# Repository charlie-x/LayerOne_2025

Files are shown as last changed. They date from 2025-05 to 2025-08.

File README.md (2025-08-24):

# LayerOne 2025 GLiTCh BadgE

later on there are ai generated docs...

altium link.. there is an eror on one of the leds on the charlieplex'd leds...
also the 3 pin JST SWD is reversed
.
https://365.altium.com/files/01BF9671-6FB8-4A9E-9FD1-49A52BA8D165

first flash drive appears as RPI-RP2 copy the uf2 file to it, after that use the system command to reboot to the dfu or hold the RP-BOOT button during power on or a reset cycle

the pico-ice can be used to test the  fpga.

https://a360.co/4dxIxcs
terminal is CR, so do cr/lf conversion.

for 3v3 control the pads need to be soldered on the pcb,

switch_pwr  
short 1-2


glitch_ctrl
solder all three
short 1-2-3


3cv3_ctrl
short 1-2-3


fet
short 1-2-3


https://a360.co/4dxIxcs

thea re two pots vr1, vr2 , vr1 changes run votlage of vtg, vr2 controls the low voltage

diag scripts will find

Serial Ports for CMSIS-DAP
==========================

Found serial ports:
crw-rw-rw-  1 root  wheel  0x9000003 May 25 08:40 /dev/cu.usbmodem1202

first serial port is the CDC
crw-rw-rw-  1 root  wheel  0x9000005 May 25 08:40 /dev/cu.usbmodem14301

is for hook up to the fpga etc
crw-rw-rw-  1 root  wheel  0x9000009 May 25 08:40 /dev/cu.usbmodem14303

adc streaming , two adc's interlevaed see the adc python script

crw-rw-rw-  1 root  wheel  0x9000007 May 25 08:40 /dev/cu.usbmodem14305

the adc streaming is seperate and always runs

// run it
python adc_stream_reader.py /dev/cu.usbmodem14305

// pack ADC values into buffer
 - #define HEADER_BYTE 0xAA
 - #define PACKET_SIZE 5
 - 
 - void pack_adc_values(uint16_t _adc0, uint16_t _adc1, uint8_t seq, uint8_t* buffer) {
 -    buffer[0] = HEADER_BYTE;                      // header byte for synchronization
 -    buffer[1] = seq;                              // sequence number
 -     buffer[2] = _adc0 & 0xFF;                      // low 8 bits of adc0
 -     buffer[3] = ((_adc0 >> 8) & 0x0F) |            // high 4 bits of adc0
 -                 ((_adc1 & 0x0F) << 4);             // low 4 bits of adc1
 -     buffer[4] = (_adc1 >> 4) & 0xFF;               // high 8 bits of adc1
 - }



tats for LayerOne2025 codebase:

  Files by type:
  - C (.c): 57 files
  - Headers (.h): 48 files
  - Python (.py): 25 files
  - Markdown (.md): 17 files
  - Shell scripts (.sh): 8 files

  Code metrics:
  - Total lines of code: ~30,383 lines
  - Total commits: 82
  - Contributors: 2 (charliex: 82)

  Top directories:
  - Root directory (372 files)
  - cli/ (42 files)
  - docs/ (12 files)

## Overview

The LayerOne 2025 GLiTCh BadgE is a versatile hardware hacking platform designed for security researchers, hardware enthusiasts, and anyone interested in exploring digital electronics. It combines a powerful RP2040 microcontroller with specialized hardware for glitching, debugging, and interfacing with other devices.

## Features

- **RP2040 Microcontroller** - Dual-core ARM Cortex-M0+ processor
- **ICE40 FPGA** - Programmable logic for custom hardware implementations
- **Voltage Glitcher** - For performing precise voltage glitching attacks
- **Crowbar Circuit** - For power line manipulation
- **SWD Interface** - For debugging ARM-based targets
- **AVRISP** - For programming AVR microcontrollers
- **Analog Monitoring** - For capturing and analyzing signals
- **Multiple USB Modes** - Normal, DAP, and DFU modes for different use cases
- **Basic Logic Analyser** - Simple 12 bit LA at about 10khz
  
## Documentation

Comprehensive documentation is available in the [docs](docs/) directory:

- [Quick Start Guide](docs/quick_start.md) - Get up and running with your badge
- [CLI User Guide](docs/cli_user_guide.md) - Learn how to use the Command Line Interface
- [USB Modes Guide](docs/usb_modes_guide.md) - Understand the different USB modes
- [Hardware Hacking Guide](docs/hardware_hacking_guide.md) - Explore the hardware hacking features
- [Glitching Techniques Guide](docs/glitching_techniques.md) - Detailed guide on voltage, reset, and crowbar glitching
- [ADC Signal Analysis Guide](docs/adc_signal_analysis.md) - How to use the ADC for signal capture and analysis
- [AVRISP Programming Guide](docs/avrisp_programming_guide.md) - Program AVR microcontrollers with the badge
- [Documenting Research](docs/documenting_research.md) - Best practices for documenting hardware security research
- [Command Reference](docs/command_reference.md) - Quick reference for all CLI commands
- [Case Studies](docs/case_studies/README.md) - Real-world examples of hardware security vulnerabilities
  - [nRF52 Glitch Attack](docs/case_studies/nrf52_glitch_attack.md) - Voltage glitching attack on Nordic's BLE SoC

## Getting Started

### Prerequisites

- Python 3.6 or higher
- PySerial library (`pip install pyserial`)
- PyOCD for debugging (`pip install pyocd`)

### Installation

1. Clone this repository:
   ```
   git clone git@github.com:charlie-x/LayerOne_2025.git
   cd LayerOne_2025
   ```

2. Connect your badge to your computer using a USB-C cable
   Either use the RP-BOOT switch to put the badge into RPI-RP2 mode while its in reset, or switch on. or if its already flashed you can use system dfu command on the badge itself, copy the uf2/layerOne2025.uf2 file to the RPI-RP2 folder, use -X if you use cp in Mac OS
  
4. Run the CLI terminal:
   ```
   python3 cli_terminal.py
   ```

### Basic Usage

Once connected to the CLI, you can use commands like:

```
help            # Show available commands
status          # Show badge status
rgb on          # Turn on the RGB LED
usb mode dap    # Switch to DAP mode
```

For a complete list of commands, see the [Command Reference](docs/command_reference.md).

## USB Modes

The badge supports three USB modes:

1. **Normal Mode** (default) - 3 CDC interfaces + Mass Storage
2. **DAP Mode** - CMSIS-DAP debugging interface + CDC
3. **DFU Mode** - Device Firmware Update mode

To switch between modes, use the `usb mode` command:

```
usb mode normal     # Switch to normal mode
usb mode dap        # Switch to DAP mode
usb mode dfu        # Switch to DFU mode
```

## Logic Analyser mode

use command 

adc_stream la



## Development

### Building the Firmware

To build the firmware:

```
./build.sh
```

### Flashing the Firmware

To build and flash the firmware:

```
./build_and_flash.sh
```

### Running Tests

To run the USB mode tests:

```
python3 test_usb_modes.py
```

## Contributing

We welcome contributions to improve the badge and its documentation! Please see the [Contributing Guide](docs/contributing.md) for details on how to contribute.

## License

The LayerOne 2025 GLiTCh BadgE firmware and hardware designs are licensed under [MIT License](https://opensource.org/licenses/MIT).

## Acknowledgments

The LayerOne 2025 GLiTCh BadgE was created by NullSpaceLabs for the LayerOne 2025 conference. Special thanks to all the contributors and the hardware hacking community for their support and inspiration.

## Contact

- Website: [nullspacelabs.com](https://nullspacelabs.com)
- Email: [info@nullspacelabs.com](mailto:info@nullspacelabs.com)
- Twitter: [@nullspacelabs](https://twitter.com/nullspacelabs)

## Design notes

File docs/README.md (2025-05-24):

# LayerOne 2025 GLiTCh BadgE Documentation

Welcome to the official documentation for the LayerOne 2025 GLiTCh BadgE! This documentation will help you get the most out of your badge and explore its many features.

## About the Badge

The LayerOne 2025 GLiTCh BadgE is a versatile hardware hacking platform designed for security researchers, hardware enthusiasts, and anyone interested in exploring digital electronics. It combines a powerful RP2040 microcontroller with specialized hardware for glitching, debugging, and interfacing with other devices.



## Documentation Guides

### Getting Started

- [Quick Start Guide](quick_start.md) - Get up and running with your badge
- [CLI User Guide](cli_user_guide.md) - Learn how to use the Command Line Interface
- [USB Modes Guide](usb_modes_guide.md) - Understand the different USB modes and how to use them

### Features and Capabilities

- [Hardware Hacking Guide](hardware_hacking_guide.md) - Explore the hardware hacking features
- [Glitching Techniques Guide](glitching_techniques.md) - Detailed guide on voltage, reset, and crowbar glitching
- [ADC Signal Analysis Guide](adc_signal_analysis.md) - How to use the ADC for signal capture and analysis
- [AVRISP Programming Guide](avrisp_programming_guide.md) - Program AVR microcontrollers with the badge
- [Documenting Research](documenting_research.md) - Best practices for documenting hardware security research
- [FPGA Programming Guide](fpga_guide.md) - Learn how to program the onboard FPGA
- [Debugging Guide](debugging_guide.md) - Use the badge as a debugging tool

### Development

- [Firmware Development](firmware_dev.md) - Develop custom firmware for the badge
- [Hardware Reference](hardware_reference.md) - Technical details about the badge hardware
- [API Reference](api_reference.md) - Software API documentation

### Case Studies

- [Hardware Security Case Studies](case_studies/README.md) - Real-world examples of hardware security vulnerabilities
  - [nRF52 Glitch Attack](case_studies/nrf52_glitch_attack.md) - Voltage glitching attack on Nordic's BLE SoC

## Command Reference

For a quick reference of all available CLI commands, see the [Command Reference](command_reference.md).

## USB Modes

The badge supports three USB modes:

1. **Normal Mode** - 3 CDC interfaces + Mass Storage
2. **DAP Mode** - CMSIS-DAP debugging interface + CDC
3. **DFU Mode** - Device Firmware Update mode

For details on how to use these modes, see the [USB Modes Guide](usb_modes_guide.md).

## Hardware Hacking Features

The badge includes several specialized hardware features:

- Voltage Glitcher
- Crowbar Circuit
- SWD Interface
- AVRISP
- Analog Monitoring
- Programmable FPGA

For details on how to use these features, see the [Hardware Hacking Guide](hardware_hacking_guide.md).

## Community Resources

- [Official Website](https://nullspacelabs.com)
- [GitHub Repository](https://github.com/nullspacelabs/layerOne2025)
- [Community Forum](https://forum.nullspacelabs.com)
- [Discord Channel](https://discord.gg/nullspacelabs)

## Contributing

We welcome contributions to improve the badge and its documentation! Please see the [Contributing Guide](contributing.md) for details on how to contribute.

## License

The LayerOne 2025 GLiTCh BadgE documentation is licensed under [CC BY-SA 4.0](https://creativecommons.org/licenses/by-sa/4.0/).

The firmware and hardware designs are licensed under [MIT License](https://opensource.org/licenses/MIT).

## Acknowledgments

The LayerOne 2025 GLiTCh BadgE was created by NullSpaceLabs for the LayerOne 2025 conference. Special thanks to all the contributors and the hardware hacking community for their support and inspiration.

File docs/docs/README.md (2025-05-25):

# LayerOne 2025 GLiTCh BadgE Documentation

Welcome to the official documentation for the LayerOne 2025 GLiTCh BadgE! This documentation will help you get the most out of your badge and explore its many features.

## About the Badge

The LayerOne 2025 GLiTCh BadgE is a versatile hardware hacking platform designed for security researchers, hardware enthusiasts, and anyone interested in exploring digital electronics. It combines a powerful RP2040 microcontroller with specialized hardware for glitching, debugging, and interfacing with other devices.



## Documentation Guides

### Getting Started

- [Quick Start Guide](quick_start.md) - Get up and running with your badge
- [CLI User Guide](cli_user_guide.md) - Learn how to use the Command Line Interface
- [USB Modes Guide](usb_modes_guide.md) - Understand the different USB modes and how to use them

### Features and Capabilities

- [Hardware Hacking Guide](hardware_hacking_guide.md) - Explore the hardware hacking features
- [Glitching Techniques Guide](glitching_techniques.md) - Detailed guide on voltage, reset, and crowbar glitching
- [ADC Signal Analysis Guide](adc_signal_analysis.md) - How to use the ADC for signal capture and analysis
- [AVRISP Programming Guide](avrisp_programming_guide.md) - Program AVR microcontrollers with the badge
- [Documenting Research](documenting_research.md) - Best practices for documenting hardware security research

### Development

### Case Studies

- [Hardware Security Case Studies](case_studies/README.md) - Real-world examples of hardware security vulnerabilities
  - [nRF52 Glitch Attack](case_studies/nrf52_glitch_attack.md) - Voltage glitching attack on Nordic's BLE SoC

## Command Reference

For a quick reference of all available CLI commands, see the [Command Reference](command_reference.md).

## USB Modes

The badge supports three USB modes:

1. **Normal Mode** - 3 CDC interfaces + Mass Storage
2. **DAP Mode** - CMSIS-DAP debugging interface + CDC
3. **DFU Mode** - Device Firmware Update mode

Switch between modes using:
```
usb mode normal    # Normal mode (default)
usb mode dap       # CMSIS-DAP mode
usb mode dfu       # Firmware update mode
```

For details on how to use these modes, see the [USB Modes Guide](usb_modes_guide.md).

## Hardware Hacking Features

The badge includes several specialised hardware features:

- **Voltage Glitcher** - Precise voltage glitching attacks
- **Crowbar Circuit** - Power line manipulation
- **SWD Interface** - ARM Cortex-M debugging
- **AVRISP/AVRISP2** - AVR microcontroller programming
- **Analog Monitoring** - ADC for signal capture and analysis
- **ICE40 FPGA** - Programmable logic for custom implementations
- **GPIO Control** - Flexible pin control and interfacing
- **Script System** - Automated command execution

For details on how to use these features, see the [Hardware Hacking Guide](hardware_hacking_guide.md).

## Community Resources

- [Official Website](https://nullspacelabs.com)
- [GitHub Repository](https://github.com/nullspacelabs/layerOne2025)
- [Community Forum](https://forum.nullspacelabs.com)
- [Discord Channel](https://discord.gg/nullspacelabs)

## Contributing

We welcome contributions to improve the badge and its documentation! Please see the [Contributing Guide](contributing.md) for details on how to contribute.

## License

The LayerOne 2025 GLiTCh BadgE documentation is licensed under [CC BY-SA 4.0](https://creativecommons.org/licenses/by-sa/4.0/).

The firmware and hardware designs are licensed under [MIT License](https://opensource.org/licenses/MIT).

## Acknowledgments

The LayerOne 2025 GLiTCh BadgE was created by NullSpaceLabs for the LayerOne 2025 conference. Special thanks to all the contributors and the hardware hacking community for their support and inspiration.

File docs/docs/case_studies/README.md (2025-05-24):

# LayerOne 2025 GLiTCh BadgE - Hardware Security Case Studies

This directory contains case studies of real-world hardware security vulnerabilities and how they can be explored using the LayerOne 2025 GLiTCh BadgE. These case studies provide practical examples of the techniques described in the main documentation.

## Available Case Studies

### [nRF52 Glitch Attack](nrf52_glitch_attack.md)

A detailed examination of the voltage glitching vulnerability discovered in Nordic Semiconductor's nRF52 series of Bluetooth Low Energy SoCs. This case study covers:

- Background on the nRF52 and its security features
- Technical details of the vulnerability
- Step-by-step procedure for reproducing the attack with the GLiTCh BadgE
- Analysis of why the attack works
- Countermeasures and lessons learned

## Purpose of Case Studies

These case studies serve several important purposes:

1. **Educational Value**: They provide concrete examples of hardware security concepts
2. **Practical Application**: They demonstrate how to apply the badge's features to real-world scenarios
3. **Research Guidance**: They offer methodologies that can be adapted to other targets
4. **Documentation Examples**: They show how to document hardware security research effectively

## Responsible Use

The information in these case studies is provided for educational and research purposes only. When reproducing these attacks or applying similar techniques to other devices:

1. Only test devices you own or have explicit permission to test
2. Follow responsible disclosure practices if you discover new vulnerabilities
3. Consider the legal and ethical implications of your research
4. Document your findings thoroughly and accurately

## Contributing Case Studies

We welcome contributions of additional case studies. If you've used the LayerOne 2025 GLiTCh BadgE to explore hardware security vulnerabilities, consider documenting your work and submitting it as a case study.

Guidelines for case study submissions:

1. Follow the format of existing case studies
2. Include clear setup instructions specific to the GLiTCh BadgE
3. Provide background information on the target device
4. Document the attack procedure in detail
5. Include analysis of why the attack works
6. Discuss countermeasures and lessons learned
7. Cite references and prior work appropriately

## Planned Future Case Studies

We plan to add more case studies covering:

- Glitching attacks on secure bootloaders
- Power analysis of cryptographic implementations
- Fault injection in smart cards
- Clock glitching techniques
- Combined glitching and side-channel attacks

Check back regularly for updates, or subscribe to the repository for notifications of new case studies.

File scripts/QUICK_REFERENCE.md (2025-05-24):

# LayerOne 2025 Badge Scripting Language - Quick Reference

## Basic Syntax

- One command per line
- Lines starting with `#` are comments
- Variables are created automatically when assigned
- No declaration needed for variables
- Case-sensitive

## Commands

### System Commands

| Command | Description | Example |
|---|---|---|
| `sleep <time>[ms|us|ns]` | Pause execution | `sleep 100ms` |
| `print <text>` | Output text | `print "Hello, world!"` |
| `exec <command>` | Execute system command | `exec status` |

### GPIO Commands

| Command | Description | Example |
|---|---|---|
| `pin <number> out` | Set pin as output | `pin 25 out` |
| `pin <number> in` | Set pin as input | `pin 2 in` |
| `pin <number> high` | Set pin high | `pin 25 high` |
| `pin <number> low` | Set pin low | `pin 25 low` |
| `pin <number> pullup` | Enable pullup resistor | `pin 2 pullup` |
| `pin <number> pulldown` | Enable pulldown resistor | `pin 2 pulldown` |
| `pin <number> nopull` | Disable pull resistors | `pin 2 nopull` |
| `pin <number> -> <var>` | Read pin state to variable | `pin 2 -> button_state` |

### ADC Commands

| Command | Description | Example |
|---|---|---|
| `adc init <channel>` | Initialize ADC channel | `adc init 0` |
| `adc temp_init` | Initialize temperature sensor | `adc temp_init` |
| `adc <channel> -> <var>` | Read ADC value to variable | `adc 0 -> pot_value` |
| `adc temp -> <var>` | Read temperature to variable | `adc temp -> temp_raw` |

### Control Flow

| Command | Description | Example |
|---|---|---|
| `if <condition>` | Start conditional block | `if pot_value > 100` |
| `else` | Alternative execution path | `else` |
| `endif` | End conditional block | `endif` |
| `loop <count>` | Loop a block of code | `loop 10` |
| `endloop` | End loop block | `endloop` |
| `goto <label>` | Jump to label | `goto start` |
| `<label>:` | Define a label | `start:` |

### Variables and Expressions

| Command | Description | Example |
|---|---|---|
| `<expr> -> <var>` | Assign value to variable | `pot_value * 2 -> doubled_value` |
| `$result` | Special variable with last result | `$result -> last_command_result` |

## Operators

### Arithmetic Operators

| Operator | Description | Example |
|---|---|---|
| `+` | Addition | `a + b -> c` |
| `-` | Subtraction | `a - b -> c` |
| `*` | Multiplication | `a * b -> c` |
| `/` | Division | `a / b -> c` |

### Comparison Operators

| Operator | Description | Example |
|---|---|---|
| `==` | Equal to | `if a == b` |
| `!=` | Not equal to | `if a != b` |
| `<` | Less than | `if a < b` |
| `>` | Greater than | `if a > b` |
| `<=` | Less than or equal to | `if a <= b` |
| `>=` | Greater than or equal to | `if a >= b` |

## Examples

### Blink LED

```
# Blink LED on pin 25
pin 25 out

loop 10
    pin 25 high
    print "LED on"
    sleep 500ms
    pin 25 low
    print "LED off"
    sleep 500ms
endloop
```

### Read Button and Control LED

```
# Set up pins
pin 2 in
pin 2 pullup
pin 25 out

loop 100
    pin 2 -> button
    
    if button == 0
        pin 25 high
        print "Button pressed, LED on"
    else
        pin 25 low
        print "Button released, LED off"
    endif
    
    sleep 10ms
endloop
```

### Read ADC and Control LED Brightness

```
# ADC controlled LED
adc init 0
pin 25 out

loop 100
    adc 0 -> pot_value
    
    if pot_value > 512
        pin 25 high
        print "LED on"
    else
        pin 25 low
        print "LED off"
    endif
    
    sleep 100ms
endloop
```

### Temperature Monitor

```
# Temperature monitor
adc temp_init

loop 60
    adc temp -> temp_raw
    
    # Convert raw value to temperature
    temp_raw * 3300 / 4096 -> millivolts
    millivolts - 706 -> adjusted
    adjusted / 1.721 -> celsius
    
    print "Temperature: " celsius " C"
    
    if celsius > 30
        print "Warning: High temperature!"
    endif
    
    sleep 1000ms
endloop
```

## Limitations

- Maximum script size: 256 lines
- Maximum line length: 128 characters
- Maximum variables: 32
- Maximum labels: 32
- Maximum call stack depth: 16
- Maximum variable name length: 16 characters
- Maximum string length: 64 characters
- Only integer and string data types
- Limited error reporting
- No functions or subroutines
- No arrays or complex data structures

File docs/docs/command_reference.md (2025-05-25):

# LayerOne 2025 GLiTCh BadgE - Command Reference

This document provides a quick reference for all CLI commands available on the LayerOne 2025 GLiTCh BadgE.

## Command Syntax

Commands follow this general syntax:
```
command [subcommand] [parameters]
```

For detailed help on any command, use:
```
help [command]
```

## General Commands

| Command | Description | Example |
|---|---|---|
| `help [command]` | Show help for all commands or a specific command | `help usb` |
| `status [subsystem]` | Show status of all systems or a specific subsystem | `status gpio` |

## Hardware Control

### RGB LED Control

| Command | Description | Example |
|---|---|---|
| `rgb on` | Turn on all RGB LEDs | `rgb on` |
| `rgb off` | Turn off all RGB LEDs | `rgb off` |
| `rgb r` | Toggle red LED | `rgb r` |
| `rgb g` | Toggle green LED | `rgb g` |
| `rgb b` | Toggle blue LED | `rgb b` |
| `rgb pwm:r,g,b` | Set PWM brightness (0.0-1.0) | `rgb pwm:1.0,0.5,0.0` |

### Power Control

| Command | Description | Example |
|---|---|---|
| `3v3 on` | Turn on the 3.3V rail | `3v3 on` |
| `3v3 off` | Turn off the 3.3V rail | `3v3 off` |

### GPIO Control

| Command | Description | Example |
|---|---|---|
| `gpio` | Show status of all GPIO pins | `gpio` |
| `gpio set <pin> <action>` | Control individual pins | `gpio set 16 high` |
| `pins` | Alias for the `gpio` command | `pins` |

**GPIO Actions:**
- `input` - Set pin as input
- `output [value]` - Set as output with optional value
- `function <func>` - Set pin function
- `high/1` - Set pin high
- `low/0` - Set pin low
- `reset` - Reset pin to default state

## FPGA Commands

| Command | Description | Example |
|---|---|---|
| `ice reset on\|off\|pulse` | Control FPGA reset pin | `ice reset pulse` |
| `ice clock on\|off` | Control 12MHz clock | `ice clock on` |
| `ice done` | Check DONE signal | `ice done` |
| `ice status` | Show FPGA status | `ice status` |
| `ice init` | initialise FPGA interfaces | `ice init` |
| `ice start [source]` | Start FPGA (spi, nvcm, flash) | `ice start spi` |
| `ice stop` | Stop FPGA | `ice stop` |
| `ice spi init\|deinit\|test\|status` | SPI interface control | `ice spi init` |

## Glitching Commands

| Command | Description | Example |
|---|---|---|
| `glitch delay <us>` | Set delay in microseconds | `glitch delay 100` |
| `glitch duration <us>` | Set duration in microseconds | `glitch duration 10` |
| `glitch trigger` | Trigger the glitch generator | `glitch trigger` |
| `glitch status` | Show current settings | `glitch status` |
| `g` | Shortcut to trigger the glitch generator | `g` |

## Crowbar Commands

| Command | Description | Example |
|---|---|---|
| `crowbar delay <us>` | Set delay in microseconds | `crowbar delay 100` |
| `crowbar duration <us>` | Set duration in microseconds | `crowbar duration 5` |
| `crowbar trigger` | Trigger the crowbar circuit | `crowbar trigger` |
| `crowbar status` | Show current settings | `crowbar status` |
| `c` | Shortcut to trigger the crowbar circuit | `c` |

## ADC Commands

| Command | Description | Example |
|---|---|---|
| `adc voltage\|current\|all` | Read ADC values | `adc voltage` |
| `adc_stream start\|stop\|status` | Control ADC streaming to CDC2 | `adc_stream start` |

## Communication Interfaces

### UART Commands

| Command | Description | Example |
|---|---|---|
| `uart send <text>` | Send text to debug UART | `uart send "Hello, World!"` |
| `uart read` | Read from debug UART | `uart read` |

### SWD Commands

| Command | Description | Example |
|---|---|---|
| `swd reset` | Reset SWD interface | `swd reset` |
| `swd read <len>` | Read bytes from SWD | `swd read 4` |
| `swd write <bytes>` | Write hex bytes to SWD | `swd write 0x01 0x02` |
| `swd idcode` | Read CPU ID code | `swd idcode` |

### AVRISP Commands

**Standard AVRISP (fixed pins):**

| Command | Description | Example |
|---|---|---|
| `avrisp init\|deinit` | initialise/deinitialise interface | `avrisp init` |
| `avrisp detect` | Detect AVR chip | `avrisp detect` |
| `avrisp fuses read\|write` | Fuse operations | `avrisp fuses read` |
| `avrisp erase` | Erase chip | `avrisp erase` |
| `avrisp program <file>` | Program hex file | `avrisp program firmware.hex` |
| `avrisp verify <file>` | Verify hex file | `avrisp verify firmware.hex` |
| `avrisp run` | Run AVRISP service on CDC1 | `avrisp run` |

**Configurable AVRISP2/AB:**

| Command | Description | Example |
|---|---|---|
| `avrisp2 init [mode]` | initialise with mode (spi\|bitbang) | `avrisp2 init spi` |
| `avrisp2 init pins <assignments>` | Custom pin assignments | `avrisp2 init pins sck=2 miso=3 mosi=4 reset=5` |
| `avrisp2 pins` | Show/set pin assignments | `avrisp2 pins` |
| `avrisp2 detect\|erase` | Basic operations | `avrisp2 detect` |
| `avrisp2 fuses read\|write` | Fuse operations | `avrisp2 fuses read` |
| `avrisp2 lock read\|on\|off` | Lock bit operations | `avrisp2 lock read` |
| `ab <command>` | Shortcut for avrisp2 commands | `ab detect` |

## System Commands

| Command | Description | Example |
|---|---|---|
| `system reboot` | Reboot the badge | `system reboot` |
| `system dfu` | Reboot into DFU mode | `system dfu` |
| `test [component] [count]` | Run tests with optional repeat count | `test gpio 5` |
| `debug on\|off\|status` | Control debug output | `debug on` |

## USB Commands

| Command | Description | Example |
|---|---|---|
| `usb mode normal` | Switch to normal mode (3 CDC + MSC) | `usb mode normal` |
| `usb mode dap` | Switch to DAP mode (CMSIS-DAP + CDC) | `usb mode dap` |
| `usb mode dfu` | Switch to DFU mode | `usb mode dfu` |
| `usb status` | Show USB status | `usb status` |

## DAP Commands

| Command | Description | Example |
|---|---|---|
| `dap init\|deinit` | initialise/deinitialise DAP | `dap init` |
| `dap status` | Show DAP status | `dap status` |
| `dap connect\|disconnect` | Target connection control | `dap connect` |
| `dap reset` | Reset target | `dap reset` |
| `dap idcode` | Read target IDCODE | `dap idcode` |
| `dap locked` | Check if target is locked | `dap locked` |

## Interface Commands

| Command | Description | Example |
|---|---|---|
| `interface list` | List available interfaces | `interface list` |
| `interface uart0\|uart1\|usb0\|usb1\|usb2` | Switch interface | `interface uart0` |

## File System Commands

| Command | Description | Example |
|---|---|---|
| `ls` | List filesystem contents | `ls` |
| `cat <filename>` | Display file contents | `cat script.txt` |
| `exec <filename>` | Execute command file | `exec startup.txt` |
| `format` | Reinitialise filesystem (erases all) | `format` |

## Script Commands

| Command | Description | Example |
|---|---|---|
| `script run <filename>` | Run script file | `script run test.scr` |
| `script load <filename>` | Load script | `script load test.scr` |
| `script list` | List available scripts | `script list` |
| `script vars` | Show script variables | `script vars` |

## Timing Commands

| Command | Description | Example |
|---|---|---|
| `delay_ns <ns>` | Delay for nanoseconds | `delay_ns 1000` |
| `sleep_ms <ms>` | Sleep for milliseconds | `sleep_ms 100` |

## Easter Eggs

| Command | Description | Example |
|---|---|---|
| `wopr start\|stop\|status` | Control WOPR simulation | `wopr start` |

## Command Parameters

Many commands accept parameters in the following formats:

1. **Positional parameters**:
   ```
   command param1 param2
   ```

2. **Named parameters**:
   ```
   command name1=value1 name2=value2
   ```

3. **Mixed parameters**:
   ```
   command param1 name2=value2
   ```

## Parameter Types

| Type | Description | Example |
|---|---|---|
| Integer | Whole number | `123`, `0x7B` (hex) |
| Float | Decimal number | `3.14` |
| String | Text (quote if it contains spaces) | `"Hello World"` |
| Boolean | True/false value | `true`, `false`, `1`, `0` |
| Pin | GPIO pin number | `16` |
| Address | Memory address | `0x20000000` |

## Common Parameter Names

| Name | Description | Example |
|---|---|---|
| `width` | Width of pulse in clock cycles | `width=10` |
| `delay` | Delay in clock cycles | `delay=100` |
| `repeat` | Number of repetitions | `repeat=3` |
| `trigger` | Trigger source | `trigger=gpio` |
| `pin` | GPIO pin number | `pin=16` |
| `edge` | Edge type for trigger | `edge=rising` |
| `channel` | ADC channel | `channel=0` |
| `baud` | Baud rate for UART | `baud=115200` |
| `tx` | TX pin for UART | `tx=0` |
| `rx` | RX pin for UART | `rx=1` |

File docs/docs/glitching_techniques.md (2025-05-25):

# LayerOne 2025 GLiTCh BadgE - Glitching Techniques Guide

## Introduction

This guide provides detailed information on how to perform various glitching attacks using the LayerOne 2025 GLiTCh BadgE. Glitching is a technique used in hardware security research to manipulate a device's operation by introducing intentional faults, potentially bypassing security measures or causing unexpected behavior.

## Types of Glitching

The badge supports several types of glitching techniques:

1. **Voltage Glitching**: Briefly disrupting the target's power supply voltage
2. **Clock Glitching**: Manipulating the clock signal to cause timing faults
3. **Reset Glitching**: Manipulating the reset line to cause partial resets
4. **Crowbar Glitching**: Using the crowbar circuit to create power shorts
5. **Electromagnetic Glitching**: Using external EM pulses (with additional hardware)

## Hardware Setup

### General Setup

1. Connect your target device to the badge:
   - Target VCC → Badge glitch output
   - Target GND → Badge GND
   - (Optional) Target clock → Badge clock output
   - (Optional) Target reset → Badge reset output

2. Connect monitoring equipment:
   - Badge ADC inputs → Target test points
   - (Optional) External oscilloscope → Badge test points

### Voltage Glitching Setup

For voltage glitching, the badge provides a controlled power output that can be briefly disrupted:

```
┌─────────┐           ┌─────────┐
│         │  Glitch   │         │
│  Badge  ├───Output──┤  Target │
│         │           │         │
└────┬────┘           └────┬────┘
     │                     │
     └─────────GND─────────┘
```

### Crowbar Glitching Setup

For crowbar glitching, the badge can briefly short the target's power supply:

```
┌─────────┐           ┌─────────┐
│         │  VCC      │         │
│  Badge  ├───Output──┤  Target │
│         │           │         │
└────┬────┘           └────┬────┘
     │      Crowbar        │
     └─────Connection──────┘
```

### Reset Glitching Setup

For reset glitching, connect the badge to the target's reset line:

```
┌─────────┐           ┌─────────┐
│         │  Reset    │         │
│  Badge  ├───Output──┤  Target │
│         │           │         │
└────┬────┘           └────┬────┘
     │                     │
     └─────────GND─────────┘
```

## Voltage Glitching Techniques

Voltage glitching involves briefly disrupting the target's power supply to cause instruction skips or memory corruption.

### Basic Voltage Glitch

1. Configure the glitcher:
   ```
   glitch setup width=10 delay=100 repeat=1
   ```

2. Arm the glitcher:
   ```
   glitch arm
   ```

3. Trigger the glitch:
   ```
   glitch trigger
   ```

### Timing-Based Voltage Glitch

To target specific operations, you need to time the glitch precisely:

1. Configure the glitcher with external trigger:
   ```
   glitch delay 10      # Set delay to 10 microseconds
   glitch duration 5    # Set duration to 5 microseconds
   ```

2. Connect monitoring to observe the target's operation

3. Trigger the glitch at the right moment:
   ```
   glitch trigger
   ```
   
   Or use the shortcut:
   ```
   g
   ```

### Glitch Parameter Tuning

Effective glitching requires finding the right parameters. Start with:

1. **Duration**: 5-20 microseconds
2. **Delay**: 0-200 microseconds  

Then perform manual parameter sweeps:

```
glitch delay 50       # Start with 50µs delay
glitch duration 10    # Start with 10µs duration
g                     # Test
glitch delay 60       # Try different delay
g                     # Test again
```

Monitor the target's response to find successful parameters.

## Crowbar Glitching Techniques

Crowbar glitching creates a more aggressive power disruption by briefly shorting the power supply.

### Basic Crowbar Glitch

1. Configure the crowbar:
   ```
   crowbar delay 100     # Set delay to 100 microseconds
   crowbar duration 5    # Set duration to 5 microseconds
   ```

2. Check the settings:
   ```
   crowbar status
   ```

3. Trigger the crowbar:
   ```
   crowbar trigger
   ```
   
   Or use the shortcut:
   ```
   c
   ```

### Timed Crowbar Glitch

For precise timing, you'll need to manually coordinate the timing:

1. Configure the crowbar parameters:
   ```
   crowbar delay 50      # Adjust based on target timing
   crowbar duration 2    # Very short duration
   ```

2. Monitor the target (e.g., via UART) and trigger at the right moment:
   ```
   c                     # Trigger when ready
   ```

### Crowbar vs. Voltage Glitching

- **Crowbar Glitching**: More aggressive, causes deeper voltage drops, works well for devices with large capacitors
- **Voltage Glitching**: More precise, allows finer control, better for sensitive devices

## Reset Glitching Techniques

Reset glitching manipulates the reset line to cause partial resets of the target.

### Basic Reset Glitch

Reset glitching can be achieved using GPIO control:

1. Connect the target's reset line to a GPIO pin on the badge

2. Control the reset line:
   ```
   gpio set 20 output 1  # Set GPIO20 as output high (inactive reset)
   gpio set 20 low       # Pull reset low (active)
   delay_ns 10000        # Brief reset pulse
   gpio set 20 high      # Release reset
   ```

### Reset Glitch During Boot

To target the boot process:

1. Configure timing and coordinate with boot sequence:
   ```
   gpio set 20 low       # Hold in reset
   sleep_ms 100          # Wait
   gpio set 20 high      # Release reset
   sleep_ms 50           # Wait for partial boot
   gpio set 20 low       # Glitch reset
   delay_ns 5000         # Brief glitch
   gpio set 20 high      # Release
   ```

2. Power cycle the target

3. Immediately arm and trigger the reset glitcher:
   ```
   reset_glitch arm
   reset_glitch trigger
   ```

## Using the ADC for Glitch Analysis

The badge's ADC can be used to monitor and analyze glitches in real-time.

### Monitoring Power During Glitches

1. Connect the target's VCC to an ADC input:
   ```
   ┌─────────┐           ┌─────────┐           ┌─────────┐
   │         │  Glitch   │         │           │         │
   │  Badge  ├───Output──┤  Target ├───VCC─────┤  Badge  │
   │         │           │         │           │   ADC   │
   └────┬────┘           └────┬────┘           └─────────┘
        │                     │
        └─────────GND─────────┘
   ```

2. Configure ADC streaming:
   ```
   adc_stream start channel=0 rate=1000000
   ```

3. Perform your glitch

4. Stop ADC streaming and save the data:
   ```
   adc_stream stop
   adc_stream save glitch_capture.csv
   ```

### Trigger-Based Capture

To capture only the glitch event:

1. Configure ADC trigger capture:
   ```
   adc capture channel=0 trigger=falling threshold=2.5 samples=1000 pretrigger=100
   ```

2. Arm the ADC capture:
   ```
   adc capture arm
   ```

3. Perform your glitch

The ADC will automatically capture when the voltage falls below 2.5V, including 100 samples before the trigger.

### Analyzing Glitch Waveforms

Key characteristics to look for in the captured waveforms:

1. **Voltage Drop**: How far the voltage drops during the glitch
2. **Glitch Duration**: The actual duration of the voltage drop
3. **Recovery Time**: How long it takes for the voltage to stabilize
4. **Ringing**: Oscillations after the glitch

Example analysis:
```
Glitch parameters: width=10, delay=100
Measured voltage drop: 3.3V → 1.2V
Measured duration: 120ns
Recovery time: 350ns
Result: Target reset successfully bypassed
```

## Documenting Glitch Attacks

### Standard Documentation Format

When documenting glitch attacks, include:

1. **Target Information**:
   - Device name and model
   - Firmware version
   - Operating conditions

2. **Setup Description**:
   - Connection diagram
   - Equipment used
   - Badge configuration

3. **Glitch Parameters**:
   - Type of glitch (voltage, crowbar, reset)
   - Width, delay, repeat settings
   - Trigger method

4. **Results**:
   - Success rate (e.g., 8/10 attempts successful)
   - Observed behavior
   - Captured waveforms

5. **Analysis**:
   - Why the glitch worked
   - Critical timing points
   - Potential countermeasures

### Example Documentation

```markdown
# Voltage Glitch Attack on XYZ Secure Microcontroller

## Target
- Device: XYZ Secure Microcontroller
- Firmware: v1.2.3
- Operating voltage: 3.3V
- Clock: 16MHz

## Setup
- LayerOne 2025 GLiTCh BadgE connected to target VCC
- Target running authentication routine
- Badge ADC0 monitoring target VCC
- Badge GPIO16 connected to target "processing" LED for trigger

## Glitch Parameters
- Type: Voltage glitch
- Width: 12 clock cycles
- Delay: 85 clock cycles after trigger
- Repeat: 1
- Trigger: Rising edge on GPIO16

## Results
- Success rate: 7/10 attempts
- When successful: Authentication bypassed, access granted
- Captured waveform shows voltage drop from 3.3V to 1.1V for 150ns
- Target continues operation after glitch without reset

## Analysis
- Glitch likely causes the comparison instruction to be skipped
- Critical timing is when the "processing" LED turns on
- The 85-cycle delay targets the exact instruction performing the password check
- Countermeasure: Implement redundant checks or glitch detection
```

## Advanced Techniques

### Multi-Stage Glitching

Some targets require multiple glitches to bypass security:

1. Configure the first glitch:
   ```
   glitch setup width=5 delay=100 name=glitch1
   ```

2. Configure the second glitch:
   ```
   glitch setup width=10 delay=500 name=glitch2
   ```

3. Create a sequence:
   ```
   glitch sequence add glitch1 glitch2 interval=1000
   ```

4. Arm and trigger the sequence:
   ```
   glitch sequence arm
   glitch sequence trigger
   ```

### Combining Glitch Types

For complex targets, combine different glitch types:

```
attack setup type=combined voltage_width=5 voltage_delay=100 reset_width=2 reset_delay=105
attack arm
attack trigger
```

This performs a voltage glitch followed immediately by a reset glitch.

### Fault Injection Campaigns

For systematic research:

1. Define parameter ranges:
   ```
   campaign setup param=width range=5:20:5 param=delay range=0:200:10 iterations=5
   ```

2. Define success criteria:
   ```
   campaign success uart="Access granted" or gpio=16:high
   ```

3. Run the campaign:
   ```
   campaign start
   ```

4. Analyze results:
   ```
   campaign report
   ```

## Troubleshooting

### Glitch Not Working

1. **No Effect on Target**:
   - Increase glitch width
   - Decrease power supply capacitance on target
   - Try crowbar instead of voltage glitch

2. **Target Always Resets**:
   - Decrease glitch width
   - Increase delay
   - Add capacitance to target

3. **Inconsistent Results**:
   - Improve trigger timing
   - Stabilize target operating conditions
   - Use ADC to verify glitch timing

## Conclusion

Glitching is both an art and a science. Success requires:

1. Understanding the target's operation
2. Precise timing and parameter tuning
3. Careful analysis of results
4. Systematic documentation

The LayerOne 2025 GLiTCh BadgE provides all the tools needed for effective glitching research. By combining different techniques and carefully analyzing the results, you can uncover vulnerabilities and better understand hardware security.

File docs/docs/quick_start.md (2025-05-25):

# LayerOne 2025 GLiTCh BadgE - Quick Start Guide

## Introduction

Welcome to your LayerOne 2025 GLiTCh BadgE! This quick start guide will help you get up and running with your badge in just a few minutes.

## What's in the Box

- LayerOne 2025 GLiTCh BadgE
- USB-C cable
- Quick reference card

## Hardware Overview



1. **USB-C Port** - Connect to your computer
2. **RGB LED** - Status indicator
3. **Reset Button** - Reset the badge
4. **User Button** - Programmable button
5. **GPIO Headers** - Connect to external devices
6. **FPGA** - ICE40 FPGA for custom logic
7. **Target Headers** - Connect to target devices for hacking
8. **Power Switch** - Turn the badge on/off

## Getting Started

### Step 1: Connect the Badge

1. Connect the USB-C cable to your badge
2. Connect the other end to your computer
3. The RGB LED should light up, indicating the badge is powered

### Step 2: Install Required Software

#### Python and Dependencies

1. Install Python 3.6 or higher:
   - Windows: Download from [python.org](https://python.org)
   - macOS: `brew install python3`
   - Linux: `sudo apt install python3 python3-pip`

2. Install required Python packages:
   ```
   pip install pyserial pyocd
   ```

### Step 3: Connect to the CLI

1. Download the badge software from [GitHub](https://github.com/nullspacelabs/layerOne2025)
2. Open a terminal and navigate to the downloaded folder
3. Run the CLI terminal script:
   ```
   python3 cli_terminal.py
   ```
4. You should see the badge prompt:
   ```
   badge>
   ```

### Step 4: Test Basic Commands

Try these commands to verify your badge is working:

```
help            # Show available commands
status          # Show badge status
rgb on          # Turn on the RGB LED
rgb off         # Turn off the RGB LED
gpio            # Show GPIO pin status
adc all         # Read all ADC channels
```

## USB Modes

The badge supports three USB modes:

1. **Normal Mode** (default) - 3 CDC interfaces + Mass Storage
2. **DAP Mode** - CMSIS-DAP debugging interface + CDC
3. **DFU Mode** - Device Firmware Update mode

To switch between modes, use the `usb mode` command:

```
usb mode normal     # Switch to normal mode
usb mode dap        # Switch to DAP mode
usb mode dfu        # Switch to DFU mode
```

After switching modes, the badge will reset and re-enumerate as a different USB device.

## Basic Features

### Controlling the RGB LED

```
rgb on          # Turn on all LEDs
rgb off         # Turn off all LEDs
rgb r           # Toggle red LED
rgb g           # Toggle green LED
rgb b           # Toggle blue LED
```

### Reading ADC Values

```
adc all         # Read all ADC channels
adc voltage     # Read voltage measurement
adc current     # Read current measurement
```

### Controlling GPIO Pins

```
gpio            # Show GPIO status
gpio set 16 high    # Set GPIO16 high
gpio set 17 low     # Set GPIO17 low
gpio set 18 input   # Set GPIO18 as input
```

### System Commands

```
status          # Show system status
system reboot   # Reboot the badge
test all        # Run all hardware tests
debug on        # Enable debug output
```

## Next Steps

Now that you've got the basics working, here are some next steps to explore:

1. **Read the Documentation** - Check out the [full documentation](README.md) for detailed guides
2. **Try Hardware Hacking** - Explore the [Hardware Hacking Guide](hardware_hacking_guide.md)
3. **Experiment with USB Modes** - Learn more in the [USB Modes Guide](usb_modes_guide.md)
4. **Join the Community** - Connect with other badge owners on [Discord](https://discord.gg/nullspacelabs)

## Troubleshooting

### Badge Not Detected

If your computer doesn't detect the badge:

1. Try a different USB cable
2. Try a different USB port
3. Make sure the power switch is on
4. Press the reset button

### Can't Connect to CLI

If you can't connect to the CLI:

1. Make sure the badge is properly connected
2. Check if another program is using the serial port
3. Try specifying the port manually:
   ```
   python3 cli_terminal.py /dev/your_port
   ```
   Where `/dev/your_port` is:
   - On macOS: typically `/dev/cu.usbmodem11301`
   - On Linux: typically `/dev/ttyACM0`
   - On Windows: typically `COM3`

### Badge Not Responding

If the badge is connected but not responding to commands:

1. Press the reset button
2. Disconnect and reconnect the USB cable
3. Try switching USB modes:
   ```
   usb mode normal
   ```

## Getting Help

If you're still having trouble:

1. Check the [full documentation](README.md)
2. Visit the [community forum](https://forum.nullspacelabs.com)
3. Join the [Discord channel](https://discord.gg/nullspacelabs)
4. Email support at [support@nullspacelabs.com](mailto:support@nullspacelabs.com)

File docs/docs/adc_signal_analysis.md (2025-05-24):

# LayerOne 2025 GLiTCh BadgE - ADC Signal Analysis Guide

## Introduction

The LayerOne 2025 GLiTCh BadgE includes powerful Analog-to-Digital Converter (ADC) capabilities that allow you to capture, analyze, and visualize analog signals. This guide explains how to use the badge's ADC features for signal analysis, particularly in the context of hardware security research and glitching attacks.

## ADC Hardware Specifications

The badge features multiple ADC channels with the following specifications:

- **Resolution**: 12-bit (0-4095 range)
- **Input Voltage Range**: 0-3.3V
- **Maximum Sample Rate**: 1 MSPS (1 million samples per second)
- **Number of Channels**: 4 independent channels
- **Buffer Size**: 32KB per channel

## Basic ADC Usage

### Reading ADC Values

To read the current value from an ADC channel:

```
adc read [channel]
```

Examples:
```
adc read        # Read all ADC channels
adc read 0      # Read ADC channel 0
adc read 1      # Read ADC channel 1
```

This will display the current voltage level:
```
ADC Channel 0: 2.543V (3112/4095)
```

### Continuous Monitoring

For real-time monitoring of a signal:

```
adc monitor [channel] [interval]
```

Examples:
```
adc monitor 0 100     # Monitor channel 0, update every 100ms
adc monitor 1 500     # Monitor channel 1, update every 500ms
```

Press Ctrl+C to stop monitoring.

## ADC Streaming

For capturing high-speed signals, use the ADC streaming feature:

### Starting ADC Stream

```
adc_stream start [options]
```

Options:
- `channel=X`: Channel number (0-3)
- `rate=X`: Sample rate in Hz (up to 1000000)
- `buffer=X`: Buffer size in samples
- `continuous=true/false`: Continuous streaming mode

Examples:
```
adc_stream start channel=0 rate=1000000     # Stream channel 0 at 1MSPS
adc_stream start channel=1 rate=500000 buffer=16384     # Stream with custom buffer
adc_stream start channel=0,1 rate=250000     # Stream multiple channels
```

### Stopping ADC Stream

```
adc_stream stop
```

### Saving Captured Data

```
adc_stream save [filename]
```

Example:
```
adc_stream save capture.csv     # Save to CSV format
adc_stream save capture.bin     # Save to binary format
```

## Triggered Capture

For capturing specific events, use the triggered capture mode:

### Configuring Trigger

```
adc capture [options]
```

Options:
- `channel=X`: Channel number (0-3)
- `trigger=rising/falling/level`: Trigger type
- `threshold=X`: Trigger threshold voltage
- `samples=X`: Number of samples to capture
- `pretrigger=X`: Number of samples to include before trigger
- `rate=X`: Sample rate in Hz

Examples:
```
adc capture channel=0 trigger=rising threshold=2.5 samples=1000 pretrigger=100
```

This will capture 1000 samples when the signal on channel 0 crosses 2.5V with a rising edge, including 100 samples before the trigger.

### Arming the Trigger

```
adc capture arm
```

The badge will wait for the trigger condition to be met, then capture the specified number of samples.

### Checking Capture Status

```
adc capture status
```

### Saving Captured Data

```
adc capture save [filename]
```

## Signal Analysis

The badge provides built-in analysis tools for captured signals:

### Basic Statistics

```
adc analyze stats [channel]
```

This displays:
- Minimum voltage
- Maximum voltage
- Average voltage
- RMS voltage
- Standard deviation

### Frequency Analysis

```
adc analyze fft [channel]
```

This performs a Fast Fourier Transform and displays:
- Dominant frequencies
- Frequency spectrum
- Power spectral density

### Pulse Analysis

```
adc analyze pulse [channel] [threshold]
```

This analyzes digital pulses in the signal:
- Pulse count
- Pulse widths
- Duty cycle
- Rise/fall times

## Practical Applications

### Power Analysis

Monitoring power consumption can reveal information about device operation:

1. Connect the badge ADC to the target's power line through a small shunt resistor:
   ```
   ┌─────────┐     ┌───────┐     ┌─────────┐
   │         │     │ Shunt │     │         │
   │  Power  ├─────┤ 10Ω   ├─────┤  Target │
   │ Supply  │     └───┬───┘     │         │
   └─────────┘         │         └─────────┘
                       │
                       │
                  ┌────┴────┐
                  │  Badge  │
                  │   ADC   │
                  └─────────┘
   ```

2. Capture power trace during operation:
   ```
   adc capture channel=0 trigger=rising threshold=0.1 samples=10000 pretrigger=1000
   adc capture arm
   ```

3. Analyze the power trace to identify operations:
   ```
   adc analyze stats
   adc analyze fft
   ```

### Glitch Detection

Detect and analyze glitches in a system:

1. Connect the badge ADC to the target's voltage rail:
   ```
   ┌─────────┐           ┌─────────┐
   │         │           │         │
   │  Target ├───VCC─────┤  Badge  │
   │         │           │   ADC   │
   └─────────┘           └─────────┘
   ```

2. Configure high-speed capture:
   ```
   adc_stream start channel=0 rate=1000000
   ```

3. Induce a glitch (using another device or the badge's glitcher)

4. Stop streaming and analyze:
   ```
   adc_stream stop
   adc_stream save glitch.csv
   adc analyze pulse 0 2.5     # Analyze with 2.5V threshold
   ```

### Clock Analysis

Analyze clock signals for timing attacks:

1. Connect the badge ADC to the target's clock line:
   ```
   ┌─────────┐           ┌─────────┐
   │         │           │         │
   │  Target ├───CLK─────┤  Badge  │
   │         │           │   ADC   │
   └─────────┘           └─────────┘
   ```

2. Capture the clock signal:
   ```
   adc_stream start channel=0 rate=1000000
   ```

3. Analyze for jitter or irregularities:
   ```
   adc analyze pulse 0 1.65     # Analyze with mid-point threshold
   ```

## Advanced ADC Techniques

### Synchronized Capture

Synchronize ADC capture with other badge operations:

```
sync setup source=glitch target=adc_capture delay=0
sync arm
glitch trigger     # This will automatically trigger ADC capture
```

### Multi-Channel Correlation

Capture and correlate multiple signals:

```
adc_stream start channel=0,1,2 rate=500000
```

Then analyze the correlation:

```
adc analyze correlation 0 1     # Correlate channels 0 and 1
```

### Long-Term Monitoring

For monitoring signals over extended periods:

```
adc_stream start channel=0 rate=1000 continuous=true file=log.csv
```

This will continuously stream ADC data to a file until stopped.

## Visualizing ADC Data

The badge provides several ways to visualize captured data:

### Text-Based Visualization

```
adc visualize text [channel]
```

Example output:
```
2.5V ┌─────────────────────────────────────────┐
     │                ▄▄▄▄▄                    │
     │               █     █                   │
     │              █       █                  │
     │             █         █                 │
0.0V └─────────────────────────────────────────┘
      0ms                                    10ms
```

### CSV Export for External Tools

```
adc_stream save data.csv
```

You can then import this CSV into tools like:
- Excel/Google Sheets
- MATLAB/Octave
- Python (with matplotlib, numpy)
- Sigrok/PulseView

### Real-Time Plotting

For supported terminals:

```
adc plot [channel] [duration]
```

Example:
```
adc plot 0 5000     # Plot channel 0 for 5 seconds
```

## Practical Examples

### Example 1: Capturing a Voltage Glitch

1. Connect ADC0 to the target's VCC
2. Set up the glitcher:
   ```
   glitch setup width=10 delay=100
   ```
3. Configure ADC capture:
   ```
   adc capture channel=0 trigger=falling threshold=3.0 samples=1000 pretrigger=200 rate=1000000
   ```
4. Arm both systems:
   ```
   adc capture arm
   glitch arm
   ```
5. Trigger the glitch:
   ```
   glitch trigger
   ```
6. Save and analyze the capture:
   ```
   adc capture save glitch_capture.csv
   adc analyze stats
   ```

### Example 2: Power Analysis Attack

1. Connect ADC0 to the target's power line through a shunt resistor
2. Start continuous monitoring:
   ```
   adc_stream start channel=0 rate=500000
   ```
3. Trigger the cryptographic operation on the target
4. Stop streaming and save:
   ```
   adc_stream stop
   adc_stream save crypto_power_trace.csv
   ```
5. Analyze for patterns:
   ```
   adc analyze fft
   ```

### Example 3: Clock Manipulation Detection

1. Connect ADC0 to the target's clock line
2. Connect ADC1 to a trigger signal that indicates when operations start
3. Configure triggered capture:
   ```
   adc capture channel=0,1 trigger=rising trigger_channel=1 threshold=2.5 samples=10000 pretrigger=1000 rate=1000000
   ```
4. Arm the capture:
   ```
   adc capture arm
   ```
5. Start the operation on the target
6. Analyze the clock signal:
   ```
   adc analyze pulse 0 1.65
   ```

## Troubleshooting

### Signal Too Weak

If the signal is too weak:
1. Use an amplifier circuit
2. Adjust the reference voltage:
   ```
   adc setup vref=internal     # Use internal reference
   adc setup vref=external     # Use external reference
   ```

### Noisy Signal

If the signal is noisy:
1. Improve grounding
2. Enable hardware filtering:
   ```
   adc setup filter=enable
   ```
3. Use software filtering:
   ```
   adc analyze filter lowpass cutoff=10000
   ```

### Missed Triggers

If triggers are being missed:
1. Adjust the threshold
2. Use hysteresis:
   ```
   adc capture channel=0 trigger=rising threshold=2.5 hysteresis=0.2
   ```
3. Try a different trigger type

## Conclusion

The badge's ADC capabilities make it a powerful tool for signal analysis in hardware security research. By combining these features with the badge's glitching and debugging capabilities, you can perform comprehensive analysis of hardware systems and identify potential vulnerabilities.

Remember to always document your findings thoroughly, including:
- Capture settings
- Signal characteristics
- Analysis results
- Correlations with other events

This documentation will be invaluable for reproducing results and sharing your research with the community.

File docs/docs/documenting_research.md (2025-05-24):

# LayerOne 2025 GLiTCh BadgE - Documenting Hardware Security Research

## Introduction

Proper documentation is a crucial aspect of hardware security research. This guide provides a structured approach to documenting your findings when using the LayerOne 2025 GLiTCh BadgE for hardware security research, glitching attacks, and vulnerability analysis.

## Why Documentation Matters

Good documentation serves several important purposes:

1. **Reproducibility**: Allows others (or your future self) to reproduce your findings
2. **Knowledge Transfer**: Helps share techniques and discoveries with the community
3. **Evidence**: Provides proof of vulnerabilities for responsible disclosure
4. **Learning**: Helps you understand what worked, what didn't, and why
5. **Recognition**: Properly documented research is more likely to be recognized and cited

## Documentation Structure

A comprehensive hardware security research document typically includes these sections:

### 1. Executive Summary

A brief overview (1-2 paragraphs) that summarizes:
- The target device
- The vulnerability discovered
- The impact of the vulnerability
- The attack method used

Example:
```markdown
This report documents a successful voltage glitching attack against the XYZ Secure Microcontroller. 
By applying precisely timed voltage glitches during the authentication process, we were able to 
bypass the password check with a success rate of approximately 70%. This vulnerability could allow 
an attacker with physical access to gain unauthorized access to protected functionality and data.
```

### 2. Target Description

Detailed information about the target device:

- **Device Identification**:
  - Manufacturer and model
  - Hardware version
  - Firmware version
  - Serial number (if relevant)

- **Technical Specifications**:
  - Processor/microcontroller type
  - Operating voltage and frequency
  - Memory configuration
  - Security features

- **Intended Security Level**:
  - What security claims does the manufacturer make?
  - What assets is the device protecting?
  - What threat model is it designed to withstand?

- **Photos and Diagrams**:
  - Clear photos of the device
  - Block diagrams
  - Identification of key components

### 3. Setup and Methodology

Detailed description of your test setup:

- **Equipment Used**:
  - LayerOne 2025 GLiTCh BadgE configuration
  - Additional test equipment (oscilloscopes, power supplies, etc.)
  - Custom hardware or adapters

- **Physical Setup**:
  - Connection diagrams
  - Photos of the actual setup
  - Modifications made to the target (if any)

- **Software Tools**:
  - Badge firmware version
  - Scripts or tools developed for the attack
  - Analysis software used

- **Methodology**:
  - Step-by-step description of the approach
  - Initial reconnaissance
  - Parameter selection process
  - Testing procedure

Example:
```markdown
## Setup

The target device was connected to the GLiTCh BadgE as shown in Figure 1. The badge's glitch 
output was connected to the target's VCC pin through a 10Ω current-limiting resistor. The badge's 
ADC0 was connected to the target's VCC to monitor the glitch waveform, while ADC1 was connected 
to the target's UART TX line to monitor responses.

The badge was configured in normal mode with the following connections:
- Badge Glitch Out → Target VCC
- Badge GND → Target GND
- Badge GPIO16 → Target "Processing" LED (for trigger)
- Badge UART RX → Target UART TX
- Badge UART TX → Target UART RX
- Badge ADC0 → Target VCC
- Badge ADC1 → Target UART TX

## Methodology

1. Initial reconnaissance was performed by monitoring normal operation of the authentication process
2. The timing of the password verification was determined by observing the "Processing" LED
3. A parameter sweep was conducted to identify effective glitch parameters
4. Targeted glitches were applied at the identified timing window
5. Successful bypasses were verified by capturing the target's UART output
```

### 4. Attack Description

Detailed explanation of the attack:

- **Attack Type**:
  - Voltage glitching
  - Clock glitching
  - Reset glitching
  - Crowbar attack
  - Combined approach

- **Attack Parameters**:
  - Glitch width
  - Glitch delay
  - Trigger method
  - Repetition rate
  - Voltage levels

- **Attack Process**:
  - Initialization steps
  - Trigger mechanism
  - Timing considerations
  - Success criteria

- **Parameter Tuning**:
  - How parameters were selected
  - What ranges were tested
  - How optimal values were determined

Example:
```markdown
## Voltage Glitching Attack

The attack targeted the password verification routine in the authentication process. Based on 
initial analysis, the verification occurs approximately 120ms after the "Enter Password:" prompt 
is displayed, and the "Processing" LED activates during this time.

### Glitch Parameters
- Type: Voltage glitch
- Width: 12 clock cycles (~750ns at 16MHz)
- Delay: 85 clock cycles (~5.3μs) after trigger
- Trigger: Rising edge on GPIO16 (connected to "Processing" LED)
- Voltage drop: From 3.3V to approximately 1.1V

### Attack Process
1. The badge was configured to monitor the target's UART interface
2. The "login" command was sent to the target
3. When prompted for a password, an incorrect password "test123" was sent
4. The glitcher was configured to trigger on the rising edge of the "Processing" LED
5. The glitcher was armed before sending the password
6. When the LED activated, the glitch was automatically triggered
7. The target's response was captured and analyzed for success indicators
```

### 5. Results

Clear presentation of your findings:

- **Success Rate**:
  - Number of successful attempts vs. total attempts
  - Statistical analysis if applicable

- **Observed Behavior**:
  - Target's response to the attack
  - Error messages or unexpected outputs
  - Timing measurements

- **Waveforms and Captures**:
  - ADC captures of the glitch
  - Logic analyzer traces
  - UART/communication logs

- **Parameter Sensitivity**:
  - How changes in parameters affected success rate
  - Critical parameters vs. less important ones
  - Operating windows for successful attacks

Example:
```markdown
## Results

### Success Rate
The attack was attempted 50 times with the following results:
- Successful bypasses: 35 (70%)
- Failed attempts: 12 (24%)
- Target crashes: 3 (6%)

### Observed Behavior
When successful, the target responded with "Access Granted" despite the incorrect password. 
The normal authentication process takes approximately 200ms, but successful glitch attacks 
resulted in responses within 150ms, suggesting that part of the verification routine was skipped.

### Waveform Analysis
Figure 3 shows the voltage waveform captured during a successful glitch. The voltage dropped 
from 3.3V to 1.1V for approximately 750ns, followed by a recovery period of about 350ns with 
some ringing before stabilizing.

### Parameter Sensitivity
The attack showed high sensitivity to the glitch width. Values between 10-15 clock cycles 
were effective, while values outside this range either had no effect or caused the target 
to reset. The delay parameter was less critical, with successful glitches occurring in the 
range of 80-100 clock cycles after the trigger.
```

### 6. Analysis

Interpretation of your results:

- **Root Cause Analysis**:
  - Why the attack worked
  - What security mechanism was bypassed
  - Underlying hardware/software vulnerability

- **Fault Model**:
  - Type of fault induced (instruction skip, data corruption, etc.)
  - Affected component (CPU, memory, peripheral)
  - Timing of the fault relative to operations

- **Technical Explanation**:
  - Circuit behavior during the glitch
  - Software execution path analysis
  - Assembly-level explanation if available

- **Comparison with Similar Attacks**:
  - How this attack relates to known techniques
  - Novel aspects of your approach

Example:
```markdown
## Analysis

### Root Cause
The successful glitch appears to cause an instruction skip during the password comparison 
routine. Based on the timing and behavior, we believe the glitch affects the conditional 
branch instruction that would normally exit the authentication routine if the password 
is incorrect.

### Fault Model
The most likely fault model is an instruction skip affecting the CPU core. The timing 
corresponds to the execution of a branch instruction at address 0x08001A4C (identified 
through firmware analysis). When this instruction is skipped, execution continues as if 
the comparison had succeeded.

### Circuit Behavior
The voltage glitch creates a momentary brownout condition that affects the CPU's ability 
to fetch and execute instructions correctly. The relatively quick recovery (350ns) prevents 
the brownout detection circuit from triggering a full reset, allowing execution to continue 
with the skipped instruction.

### Comparison with Known Techniques
This attack is similar to documented voltage glitching attacks against other ARM Cortex-M 
based microcontrollers. However, the target's brownout detection appears to be less sensitive 
than typical implementations, making it more vulnerable to this type of attack.
```

### 7. Countermeasures

Discussion of potential mitigations:

- **Hardware Countermeasures**:
  - Improved power supply filtering
  - Voltage monitors
  - Clock monitors
  - Physical protection

- **Software Countermeasures**:
  - Redundant checks
  - Control flow integrity
  - Timing variation
  - Checksums and integrity verification

- **Effectiveness Assessment**:
  - How effective each countermeasure would be
  - Implementation complexity
  - Performance impact

Example:
```markdown
## Countermeasures

### Recommended Hardware Countermeasures
1. **Improved Power Supply Filtering**: Adding additional decoupling capacitors (100nF and 10μF) 
   close to the VCC pin would make the device more resistant to voltage glitches.
2. **Voltage Monitor**: Implementing an external voltage supervisor with a fast response time 
   (<100ns) would detect glitches and trigger a reset.

### Recommended Software Countermeasures
1. **Redundant Verification**: Implementing multiple password checks at different points in 
   the code would require multiple successful glitches to bypass.
2. **Control Flow Integrity**: Adding checksums or signatures to critical code paths would 
   detect instruction skips.
3. **Temporal Redundancy**: Repeating the verification process multiple times with delays 
   would make timing-specific glitches less effective.

### Effectiveness Assessment
The most effective approach would be a combination of hardware and software countermeasures. 
The hardware improvements would increase the difficulty of performing a successful glitch, 
while the software countermeasures would provide defense in depth if the hardware protection 
is bypassed.
```

### 8. Conclusion

Summary of your findings:

- **Key Takeaways**:
  - Most important findings
  - Significance of the vulnerability
  - Broader implications

- **Future Work**:
  - Additional tests to consider
  - Variations of the attack to explore
  - Related research directions

Example:
```markdown
## Conclusion

This research demonstrates that the XYZ Secure Microcontroller is vulnerable to voltage 
glitching attacks that can bypass its authentication mechanism. The attack has a relatively 
high success rate (70%) and requires only moderate expertise and equipment to perform.

The vulnerability undermines the security claims of the device and could allow unauthorized 
access to protected functionality and sensitive data. The most concerning aspect is that the 
attack leaves no permanent evidence, making it difficult to detect that the device has been 
compromised.

Future work should explore whether similar vulnerabilities exist in other security-critical 
operations of the device, such as encryption key handling and secure boot processes. Additionally, 
testing the proposed countermeasures would provide valuable validation of their effectiveness.
```

### 9. Appendices

Supporting information:

- **Raw Data**:
  - Complete test results
  - Parameter sweep data
  - Success rate tables

- **Code and Scripts**:
  - Badge configuration scripts
  - Analysis scripts
  - Custom tools developed

- **Additional Waveforms**:
  - Comprehensive set of captures
  - Comparison of successful vs. failed attempts
  - Annotated waveforms

- **References**:
  - Related research papers
  - Datasheets and technical documentation
  - Tools and methodologies used

## Documentation Tools

The LayerOne 2025 GLiTCh BadgE provides several features to help with documentation:

### Capture and Export

- **ADC Data Export**:
  ```
  adc_stream save capture.csv
  ```

- **Terminal Log Export**:
  ```
  log save session.txt
  ```

- **Screenshot Capture**:
  ```
  screenshot save screen.png
  ```

### Automated Documentation

- **Test Campaign Reports**:
  ```
  campaign report --format=markdown > campaign_results.md
  ```

- **Parameter Sweep Visualization**:
  ```
  glitch visualize sweep --format=heatmap > sweep_results.png
  ```

- **Session Recording**:
  ```
  session record start
  # Perform your tests
  session record stop
  session export report.md
  ```

## Best Practices

### 1. Document in Real-Time

Don't wait until after your research to document. Take notes during the process:

- Record initial observations
- Document parameter changes and results immediately
- Capture waveforms as you go
- Note unexpected behaviors when they occur

### 2. Use Standard Formats

Standardize your documentation format:

- Use consistent units (ns, μs, MHz, etc.)
- Define abbreviations and technical terms
- Use clear naming conventions for files and parameters
- Include timestamps for captures and tests

### 3. Include Metadata

Always include contextual information:

- Date and time of tests
- Environmental conditions (temperature, power supply quality)
- Badge firmware version
- Target device details
- Test equipment configuration

### 4. Visual Documentation

A picture is worth a thousand words:

- Include photos of your setup
- Use diagrams to explain connections
- Annotate waveforms with key events
- Use tables for parameter comparisons
- Create graphs for success rates and correlations

### 5. Version Control

Track changes to your documentation:

- Use version control (Git) for scripts and notes
- Date all versions of your documentation
- Note major changes between versions
- Archive raw data separately from analysis

## Example Documentation Template

```markdown
# Hardware Security Research Report

## Target Information
- Device: [Manufacturer and Model]
- Version: [Hardware/Firmware Version]
- Security Features: [List of security features]

## Test Setup
- Equipment: LayerOne 2025 GLiTCh BadgE (Firmware v1.2.3)
- Connections: [Diagram or description]
- Additional Equipment: [List any other equipment]
- Software Tools: [List software tools used]

## Methodology
1. [Step 1]
2. [Step 2]
3. [Step 3]

## Attack Parameters
- Type: [Voltage/Clock/Reset/Crowbar] Glitch
- Width: [Value] [Units]
- Delay: [Value] [Units]
- Trigger: [Description]
- [Other relevant parameters]

## Results
- Success Rate: [X/Y] attempts ([Z]%)
- Observed Behavior: [Description]
- Waveforms: [Include or reference waveforms]
- Parameter Sensitivity: [Description]

## Analysis
- Root Cause: [Description]
- Fault Model: [Description]
- Technical Explanation: [Description]

## Countermeasures
- Hardware: [List recommendations]
- Software: [List recommendations]
- Effectiveness: [Assessment]

## Conclusion
[Summary of findings and implications]

## Appendices
- Raw Data: [Links or references]
- Code: [Links or references]
- Additional Waveforms: [Links or references]
- References: [List of references]
```

## Responsible Disclosure

When documenting vulnerabilities, consider responsible disclosure:

1. **Notify the Manufacturer**:
   - Provide clear documentation
   - Include reproduction steps
   - Suggest countermeasures

2. **Establish a Timeline**:
   - Give reasonable time for fixes
   - Coordinate disclosure dates
   - Follow up on mitigation progress

3. **Limit Sensitive Details**:
   - Consider what details to include in public reports
   - Balance transparency with security
   - Focus on methodology rather than exploit details

## Conclusion

Thorough documentation is as important as the technical work itself in hardware security research. By following these guidelines, you can create comprehensive, useful documentation that enhances the value of your research and contributes to the security community's knowledge base.

The LayerOne 2025 GLiTCh BadgE's built-in documentation features make it easier to capture and organize your findings, allowing you to focus on the research while still maintaining excellent documentation practices.

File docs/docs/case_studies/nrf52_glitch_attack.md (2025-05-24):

# Case Study: nRF52 Glitch Attack

## Introduction

The nRF52 series of System-on-Chips (SoCs) from Nordic Semiconductor are widely used in IoT devices, wearables, and other Bluetooth Low Energy (BLE) applications. In 2019-2020, researchers discovered that these chips were vulnerable to voltage glitching attacks that could bypass their security features, including the readback protection that was designed to prevent extraction of firmware and sensitive data.

This case study examines this vulnerability and how it can be reproduced using the LayerOne 2025 GLiTCh BadgE.

## Background

### The nRF52 Series

The nRF52 series includes several variants (nRF52832, nRF52840, etc.) based on the ARM Cortex-M4F processor. These SoCs feature:

- 32-bit ARM Cortex-M4F CPU (64 MHz)
- Bluetooth 5.0 support
- 256 KB to 1 MB Flash memory
- 32 KB to 256 KB RAM
- Various security features including:
  - Readback protection
  - Debug access port protection
  - Memory protection units

### Security Features

The nRF52 implements several security features, with one of the most important being the APPROTECT (Access Port Protection) mechanism. When enabled, APPROTECT is supposed to prevent:

1. Reading the chip's flash memory through the debug interface
2. Debugging the processor
3. Accessing internal registers and memory

This protection is crucial for devices that store sensitive information like encryption keys, proprietary algorithms, or personal data.

## The Vulnerability

### Discovery

In 2019, researchers from Ledger (a cryptocurrency hardware wallet company) discovered that the nRF52 was vulnerable to voltage glitching attacks. The vulnerability was later independently verified by other researchers and security firms.

### Technical Details

The vulnerability exists in the hardware implementation of the APPROTECT feature. During the boot process, the nRF52 checks if APPROTECT is enabled by reading a specific register. If a precisely timed voltage glitch is applied during this check, the processor can misinterpret the value, effectively bypassing the protection.

Key aspects of the vulnerability:

1. The vulnerability is in hardware, not software
2. It affects all nRF52 series chips manufactured before the discovery
3. It cannot be fixed with a firmware update
4. It requires physical access to the device

### Impact

This vulnerability had significant implications:

1. **Firmware Extraction**: Attackers could extract proprietary firmware
2. **Key Extraction**: Cryptographic keys and secrets could be accessed
3. **IP Theft**: Proprietary algorithms and code could be stolen
4. **Device Cloning**: Devices could be cloned with extracted firmware
5. **Security Bypass**: Security features like secure boot could be circumvented

## Reproducing the Attack with the GLiTCh BadgE

The LayerOne 2025 GLiTCh BadgE is well-suited for reproducing this attack for educational and security research purposes.

### Required Equipment

- LayerOne 2025 GLiTCh BadgE
- nRF52 development board or target device
- Jumper wires
- (Optional) Logic analyzer or oscilloscope

### Physical Setup

1. Connect the badge to the nRF52 target:
   - Badge GND → nRF52 GND
   - Badge Glitch Out → nRF52 VDD
   - Badge SWD Clock → nRF52 SWDCLK
   - Badge SWD Data → nRF52 SWDIO
   - Badge ADC0 → nRF52 VDD (for monitoring)

2. Setup diagram:
   ```
   ┌─────────┐           ┌─────────┐
   │         │  Glitch   │         │
   │  Badge  ├───Output──┤  nRF52  │
   │         │           │         │
   │         │  SWDCLK   │         │
   │         ├───────────┤         │
   │         │           │         │
   │         │  SWDIO    │         │
   │         ├───────────┤         │
   │         │           │         │
   │         │  ADC0     │         │
   │         ├───────────┤         │
   │         │           │         │
   └────┬────┘           └────┬────┘
        │                     │
        └─────────GND─────────┘
   ```

### Attack Procedure

#### Step 1: Initial Reconnaissance

1. Power up the nRF52 without glitching
2. Attempt to connect via SWD:
   ```
   swd scan
   ```
3. Verify that APPROTECT is enabled (connection should fail)

#### Step 2: Configure the Glitcher

1. Set up the voltage glitcher:
   ```
   glitch setup width=5 delay=0 repeat=1
   ```

2. Configure ADC monitoring:
   ```
   adc_stream start channel=0 rate=1000000
   ```

#### Step 3: Glitch During Reset

1. Set up a script to automate the process:
   ```
   # Example script
   for delay in range(0, 200, 5):
       # Configure glitch
       send_command("glitch setup width=5 delay=" + str(delay) + " repeat=1")
       
       # Reset target
       toggle_reset()
       
       # Apply glitch
       send_command("glitch trigger")
       
       # Try to connect via SWD
       if swd_connect():
           print("Success at delay=" + str(delay))
           break
   ```

2. Run the script to find the vulnerable timing window

#### Step 4: Exploit the Vulnerability

Once the correct timing is found:

1. Apply the glitch during reset
2. Connect via SWD:
   ```
   swd connect
   ```
3. Dump the flash memory:
   ```
   swd dump 0x00000000 0x80000 firmware.bin
   ```

### Parameter Tuning

The attack requires precise timing. Typical parameters:

- **Width**: 3-10 clock cycles
- **Delay**: Varies by device, typically 50-150 clock cycles after reset
- **Voltage Drop**: From 3.3V to approximately 1.8-2.2V
- **Glitch Type**: Voltage glitch (not clock glitch)

## Analysis of the Attack

### Why It Works

The vulnerability exists because:

1. The APPROTECT check happens early in the boot process
2. The check is performed only once
3. The hardware lacks redundancy or verification for this critical security check
4. The CPU can misinterpret register values when its voltage is disturbed

### Success Rate

With properly tuned parameters, success rates of 30-70% are typical. Factors affecting success:

1. Precise timing of the glitch
2. Magnitude of the voltage drop
3. Duration of the glitch
4. Quality of the power supply
5. Specific nRF52 variant and revision

## Countermeasures

Nordic Semiconductor addressed this vulnerability in several ways:

1. **Hardware Revision**: Newer revisions of the nRF52 chips include hardware fixes
2. **Identification**: Nordic published information to identify vulnerable vs. fixed chips
3. **Recommendations**: Additional security measures were recommended for sensitive applications

For developers using potentially vulnerable nRF52 chips:

1. **Physical Security**: Make physical access to the device difficult
2. **Encrypted Storage**: Store sensitive data in encrypted form
3. **Runtime Integrity Checks**: Implement software integrity verification
4. **Layered Security**: Don't rely solely on APPROTECT

## Lessons Learned

The nRF52 glitch attack teaches several important lessons:

1. **Hardware Security is Critical**: Software security measures can be bypassed by hardware attacks
2. **Single Points of Failure**: Security should not depend on a single check
3. **Redundancy Matters**: Critical security checks should be redundant and diverse
4. **Physical Access Risks**: Physical access to devices enables powerful attack vectors
5. **Testing Limitations**: Standard security testing may not catch glitch vulnerabilities

## Conclusion

The nRF52 glitch attack represents a classic example of how hardware vulnerabilities can undermine otherwise well-designed security systems. It demonstrates the importance of considering physical attacks in security threat models, especially for devices that may be physically accessible to attackers.

The LayerOne 2025 GLiTCh BadgE provides an excellent platform for studying this and similar vulnerabilities, allowing security researchers and developers to better understand and defend against such attacks.

## References

1. Ledger Donjon, "Unfixable Seed Extraction on Trezor - A practical and reliable attack"
2. Colin O'Flynn, "Glitching the nRF52 (Nordic's BLE Chip)"
3. Nordic Semiconductor, "nRF52 Series PSA: Readback protection bypass"
4. Riscure, "Voltage glitching to bypass hardware security"
5. Ken Munro, "Breaking BLE: Extracting secrets from nRF52 chips"

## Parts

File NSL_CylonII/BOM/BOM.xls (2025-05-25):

Description | Quantity | Unit | Total | Minimum for Price Break | Digikey | Mouser | Goldmine Electronics | OEM
PCB silver | 1 | $2.00 | $2.00 | 100
CPU ATTiny2313 | 1 | $1.61 | $1.61 | 25 | ATTINY2313A-MU-ND
BATTERY CR2032 | 1 | $0.25 | $0.25 | 10 | P189-ND
RESISTOR 1206 200Ohm | 6 | $0.05 | $0.32 | 50 | RHM200ERCT-ND |  |  | MCR18EZPJ201
RESISTOR 0805 20Ohm | 1 | $0.03 | $0.03 | 1 | RMCF0805JT20R0CT-ND
CAP 0805 0.1uF | 1 | $0.04 | $0.04 | 1 | PCF1126TR-ND |  |  | ECP-U1C104MA5
SWITCH Momentary | 1 | $0.05 | $0.05 | 1000 |  |  | G13795B |  | http://www.goldmine-elec-products.com/prodinfo.asp?number=G13795B
Battery Holder CR2032 | 1 | $0.26 | $0.26 | 1 | BAT-HLD-001-ND
LED RED 1206 | 30 | $0.05 | $1.50 | 100 | 475-1407-1-ND |  |  | LG N971-KN-1-0-20-R18
Speaker | 1 | $1.89 | $1.89 | 1 | 102-1265-1-ND |  |  | CCV-084B16
Total |  |  | $7.94

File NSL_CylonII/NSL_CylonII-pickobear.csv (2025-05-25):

C1 | 0.1uF | 0603-CAP | 84963 | 83439 | 90 | 0
LED1 | NA | CHIPLED_1206 | 104140 | 93980 | 180 | 0
LED2 | NA | CHIPLED_1206 | 106680 | 93980 | 0 | 0
LED3 | NA | CHIPLED_1206 | 109220 | 93980 | 180 | 0
LED4 | NA | CHIPLED_1206 | 111760 | 93980 | 0 | 0
LED5 | NA | CHIPLED_1206 | 114300 | 93980 | 180 | 0
LED6 | NA | CHIPLED_1206 | 116840 | 93980 | 0 | 0
LED7 | NA | CHIPLED_1206 | 114300 | 76835 | 180 | 0
LED8 | NA | CHIPLED_1206 | 116840 | 76835 | 0 | 0
LED9 | NA | CHIPLED_1206 | 114300 | 71120 | 180 | 0
LED10 | NA | CHIPLED_1206 | 116840 | 71120 | 0 | 0
LED11 | NA | CHIPLED_1206 | 104140 | 88265 | 180 | 0
LED12 | NA | CHIPLED_1206 | 106680 | 88265 | 0 | 0
LED13 | NA | CHIPLED_1206 | 109220 | 88265 | 180 | 0
LED14 | NA | CHIPLED_1206 | 111760 | 88265 | 0 | 0
LED15 | NA | CHIPLED_1206 | 114300 | 88265 | 180 | 0
LED16 | NA | CHIPLED_1206 | 116840 | 88265 | 0 | 0
LED17 | NA | CHIPLED_1206 | 109220 | 71120 | 180 | 0
LED18 | NA | CHIPLED_1206 | 111760 | 71120 | 0 | 0
LED19 | NA | CHIPLED_1206 | 104140 | 82550 | 180 | 0
LED20 | NA | CHIPLED_1206 | 106680 | 82550 | 0 | 0
LED21 | NA | CHIPLED_1206 | 109220 | 82550 | 180 | 0
LED22 | NA | CHIPLED_1206 | 111760 | 82550 | 0 | 0
LED23 | NA | CHIPLED_1206 | 114300 | 82550 | 180 | 0
LED24 | NA | CHIPLED_1206 | 116840 | 82550 | 0 | 0
LED25 | NA | CHIPLED_1206 | 104140 | 76835 | 180 | 0
LED26 | NA | CHIPLED_1206 | 106680 | 76835 | 0 | 0
LED27 | NA | CHIPLED_1206 | 109220 | 76835 | 180 | 0
LED28 | NA | CHIPLED_1206 | 111760 | 76835 | 0 | 0
LED29 | NA | CHIPLED_1206 | 104140 | 71120 | 180 | 0
LED30 | NA | CHIPLED_1206 | 106680 | 71120 | 0 | 0
R1 | 220 | 1206 | 97790 | 86360 | 0 | 0
R2 | 220 | 1206 | 97790 | 88900 | 0 | 0
R3 | 220 | 1206 | 97790 | 78740 | 0 | 0
R4 | 220 | 1206 | 97790 | 81280 | 0 | 0
R5 | 220 | 1206 | 97790 | 83786 | 0 | 0
R6 | NA | 1206 | 91440 | 76200 | 270 | 0
R7 | 220 | 1206 | 97790 | 76200 | 0 | 0
S1 | NA | TACTILE_SWITCH_SMD | 91440 | 69850 | 180 | 0
S2 | NA | TACTILE_SWITCH_SMD | 91440 | 96012 | 0 | 0
S3 | NA | TACTILE_SWITCH_SMD | 91440 | 90170 | 0 | 0
U$1 | tiny2313 | MLF20 | 91440 | 82550 | 45 | 0
BAT1 | NA | SPARKFUN_BATTCON_20MM | 92202 | 82423 | 90 | 1
SG1 | NA | BUZZER-CCV | 118618 | 83312 | 90 | 1

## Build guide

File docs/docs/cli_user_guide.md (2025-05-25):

# LayerOne 2025 GLiTCh BadgE - CLI User Guide

## Introduction

The LayerOne 2025 GLiTCh BadgE is a versatile hardware hacking platform that provides a Command Line Interface (CLI) for controlling various features and functions. This guide explains how to connect to the CLI and use the available commands.

## Connecting to the CLI

### Prerequisites

- Python 3.6 or higher
- PySerial library (`pip install pyserial`)

### Connection Methods

#### 1. Using the CLI Terminal Script

The easiest way to connect to the badge is using the provided `cli_terminal.py` script:

```bash
python3 cli_terminal.py
```

This script will automatically detect your badge and establish a connection. If the script can't find your badge, you can specify the port manually:

```bash
python3 cli_terminal.py /dev/your_port
```

Where `/dev/your_port` is:
- On macOS: typically `/dev/cu.usbmodem11301`
- On Linux: typically `/dev/ttyACM0`
- On Windows: typically `COM3`

#### 2. Using a Serial Terminal

You can also use any serial terminal program (like PuTTY, screen, minicom, etc.) with these settings:
- Baud rate: 115200
- Data bits: 8
- Parity: None
- Stop bits: 1
- Flow control: None

Example with `screen` on macOS/Linux:
```bash
screen /dev/cu.usbmodem11301 115200
```

## USB Modes

The badge supports three USB modes that change how it appears to your computer:

1. **Normal Mode**: Provides 3 CDC (serial) interfaces and a Mass Storage device
2. **DAP Mode**: Provides CMSIS-DAP debugging interface and a CDC interface
3. **DFU Mode**: Device Firmware Update mode for updating the badge firmware

You can switch between these modes using the `usb mode` command (see below).

## Command Reference

### General Commands

#### `help [command]`
Displays help information for all commands or detailed help for a specific command.

Examples:
```
help            # Shows all available commands
help usb        # Shows detailed help for the usb command
help gpio       # Shows detailed help for the gpio command
```

#### `status [subsystem]`
Shows the status of all systems or a specific subsystem.

Examples:
```
status          # Shows status of all subsystems
status usb      # Shows USB status
status gpio     # Shows GPIO status
```

### Hardware Control

#### `rgb r|g|b|on|off|pwm:r,g,b`
Controls the RGB LED on the badge.

Examples:
```
rgb on          # Turn on all LEDs
rgb off         # Turn off all LEDs
rgb r           # Toggle red LED
rgb g           # Toggle green LED
rgb b           # Toggle blue LED
rgb pwm:1.0,0.5,0.0  # Set PWM brightness (0.0-1.0)
```

#### `3v3 on|off`
Controls the 3.3V power rail.

Examples:
```
3v3 on          # Turn on the 3.3V rail
3v3 off         # Turn off the 3.3V rail
```

#### `gpio`
Shows the status of all GPIO pins.

#### `gpio set <pin> <action>`
Controls individual GPIO pins.

Examples:
```
gpio set 16 high        # Set GPIO16 to high
gpio set 17 low         # Set GPIO17 to low
gpio set 18 input       # Set GPIO18 as input
gpio set 19 output 1    # Set GPIO19 as output high
gpio set 20 function 5  # Set GPIO20 to function 5
gpio set 21 reset       # Reset GPIO21 to default
```

#### `pins`
Alias for the `gpio` command.

### FPGA Control

#### `ice reset on|off|pulse`
Controls the FPGA reset pin.

Example:
```
ice reset pulse
```

#### `ice clock on|off`
Controls the 12MHz clock to the FPGA.

Example:
```
ice clock on
```

#### `ice done`
Checks the FPGA DONE signal.

#### `ice init`
initialises FPGA interfaces.

#### `ice start [source]`
Starts the FPGA from specified source (spi, nvcm, flash).

Example:
```
ice start spi
```

#### `ice stop`
Stops the FPGA.

#### `ice status`
Shows the status of the FPGA.

#### `ice spi init|deinit|test|status`
Controls the SPI interface to the FPGA.

Example:
```
ice spi init
```

### Glitching and Hardware Attacks

#### `glitch delay <us>`
Sets the glitch delay in microseconds.

Example:
```
glitch delay 100
```

#### `glitch duration <us>`
Sets the glitch duration in microseconds.

Example:
```
glitch duration 10
```

#### `glitch trigger`
Triggers the glitch generator.

#### `glitch status`
Shows the current glitch settings.

#### `g`
Shortcut to trigger the glitch generator.

#### `crowbar delay <us>`
Sets the crowbar delay in microseconds.

Example:
```
crowbar delay 100
```

#### `crowbar duration <us>`
Sets the crowbar duration in microseconds.

Example:
```
crowbar duration 5
```

#### `crowbar trigger`
Triggers the crowbar circuit.

#### `crowbar status`
Shows the current crowbar settings.

#### `c`
Shortcut to trigger the crowbar circuit.

### ADC (Analog-to-Digital Converter)

#### `adc voltage|current|all`
Reads values from the ADC.

Examples:
```
adc voltage     # Read voltage measurement
adc current     # Read current measurement
adc all         # Read all ADC channels
```

#### `adc_stream start|stop|status`
Controls streaming ADC values to the CDC2 interface.

Examples:
```
adc_stream start    # Start streaming ADC values
adc_stream stop     # Stop streaming ADC values
adc_stream status   # Show streaming status
```

### Communication Interfaces

#### `uart send <text>`
Sends text over the debug UART interface.

Example:
```
uart send "Hello, World!"
```

#### `uart read`
Reads data from the debug UART interface.

#### `swd reset`
Resets the SWD interface.

#### `swd read <len>`
Reads bytes from an SWD device.

Example:
```
swd read 4    # Read 4 bytes
```

#### `swd write <bytes>`
Writes hex bytes to an SWD device.

Example:
```
swd write 0x01 0x02 0x03 0x04
```

#### `swd idcode`
Reads the CPU ID code from an SWD device.

#### Standard AVRISP Commands

#### `avrisp init|deinit`
initialises or deinitialises the AVRISP interface (fixed pins).

#### `avrisp detect`
Detects an AVR device connected via ISP.

#### `avrisp fuses read|write`
Reads or writes AVR fuses.

#### `avrisp erase`
Erases the connected AVR device.

#### `avrisp program <file>`
Programs an AVR device with a hex file.

Example:
```
avrisp program firmware.hex
```

#### `avrisp verify <file>`
Verifies an AVR device against a hex file.

#### `avrisp run`
Runs the AVRISP service on CDC port 1.

#### Configurable AVRISP2/AB Commands

#### `avrisp2 init [mode]`
initialises AVRISP2 with specified mode (spi or bitbang).

Example:
```
avrisp2 init spi
```

#### `avrisp2 init pins <assignments>`
initialises with custom pin assignments.

Example:
```
avrisp2 init pins sck=2 miso=3 mosi=4 reset=5 power=6
```

#### `avrisp2 pins`
Shows or sets pin assignments.

#### `avrisp2 detect|erase`
Basic AVR operations with configurable pins.

#### `avrisp2 fuses read|write`
Fuse operations with configurable pins.

#### `avrisp2 lock read|on|off`
Lock bit operations.

#### `ab <command>`
Shortcut for avrisp2 commands.

Example:
```
ab detect
```

### Debugging and Development

#### `dap init|deinit`
initialises or deinitialises the CMSIS-DAP interface.

#### `dap status`
Shows the status of the CMSIS-DAP interface.

#### `dap connect|disconnect`
Connects to or disconnects from a target device.

#### `dap reset`
Resets the connected target device.

#### `dap idcode`
Reads the IDCODE from the connected target.

#### `dap locked`
Checks if the target device is locked.

#### `interface list`
Lists available communication interfaces.

#### `interface uart0|uart1|usb0|usb1|usb2`
Switches the CLI to a different interface.

Example:
```
interface uart0    # Switch CLI to UART0 interface
```

### System Commands

#### `system reboot`
Reboots the badge.

#### `system dfu`
Reboots the badge into DFU mode.

#### `test [component] [count]`
Runs tests for specific components with optional repeat count.

Examples:
```
test            # Run all tests
test gpio 5     # Test GPIO functionality 5 times
test rgb        # Test RGB LED
test glitch     # Test glitch functionality
test crowbar    # Test crowbar circuit
test adc        # Test ADC
test 3v3        # Test 3.3V rail
test all 3      # Run all tests 3 times
```

#### `debug on|off|status`
Controls debug output.

Examples:
```
debug on        # Enable debug output
debug off       # Disable debug output
debug status    # Show debug status
```

#### `usb mode normal|dap|dfu`
Switches the USB mode.

Examples:
```
usb mode normal     # Switch to normal mode (3 CDC + MSC)
usb mode dap        # Switch to DAP mode (CMSIS-DAP + CDC)
usb mode dfu        # Switch to DFU mode
```

#### `usb status`
Shows the current USB status.

### File System Commands

#### `ls`
Lists the contents of the filesystem.

#### `cat <filename>`
Displays the contents of a file.

Example:
```
cat startup.txt
```

#### `exec <filename>`
Executes commands from a file.

Example:
```
exec startup.txt
```

#### `format`
Reinitialises the filesystem (erases all files).

### Script Commands

#### `script run <filename>`
Runs a script file.

Example:
```
script run test.scr
```

#### `script load <filename>`
Loads a script file.

#### `script list`
Lists available script files.

#### `script vars`
Shows script variables.

### Timing Commands

#### `delay_ns <ns>`
Delays for a specified number of nanoseconds.

Example:
```
delay_ns 1000
```

#### `sleep_ms <ms>`
Sleeps for a specified number of milliseconds.

Example:
```
sleep_ms 100
```

### Easter Eggs

#### `wopr start|stop|status`
Controls the WOPR simulation (War Operation Plan Response).

Examples:
```
wopr start      # Start the WOPR simulation
wopr stop       # Stop the simulation
wopr status     # Show simulation status
```

## USB Mode Details

### Normal Mode
- 3 CDC interfaces:
  - CDC0: CLI interface
  - CDC1: Debug interface
  - CDC2: ADC Stream interface
- MSC (Mass Storage) device

### DAP Mode
- CMSIS-DAP interface for debugging
- CDC0: CLI interface

### DFU Mode
- Device Firmware Update mode
- Used for updating the badge firmware

## Tips and Tricks

1. **Command History**: Press the up and down arrow keys to navigate through command history.

2. **Tab Completion**: Some terminal emulators support tab completion for commands.

3. **Automatic Reconnection**: The `cli_terminal.py` script will automatically reconnect if the connection is lost.

4. **Multiple Interfaces**: In normal mode, you can connect to all three CDC interfaces simultaneously.

5. **Debugging with CMSIS-DAP**: In DAP mode, you can use tools like pyOCD or OpenOCD to debug the badge or external targets.

## Troubleshooting

### Badge Not Detected

If the badge is not detected:

1. Check the USB connection
2. Try a different USB port or cable
3. Restart the badge by unplugging and plugging it back in
4. Make sure you have the correct drivers installed (especially on Windows)

### Wrong USB Mode

If you need to change the USB mode but can't access the CLI:

1. Try connecting to a different CDC interface
2. Use the hardware reset button while holding a specific key to force a mode
3. If all else fails, reflash the firmware

### Command Not Working

If a command is not working as expected:

1. Check the command syntax using `help <command>`
2. Make sure the required hardware is connected and powered
3. Check the status of the relevant subsystem using `status <subsystem>`
4. Try rebooting the badge using `system reboot`

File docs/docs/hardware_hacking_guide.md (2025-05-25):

# LayerOne 2025 GLiTCh BadgE - Hardware Hacking Guide

## Introduction

The LayerOne 2025 GLiTCh BadgE is designed as a versatile hardware hacking platform with features specifically tailored for security research, glitching attacks, and hardware exploration. This guide explains how to use these features effectively.

## Hardware Hacking Features

The badge includes several specialized hardware features:

1. **Voltage Glitcher**: For performing precise voltage glitching attacks
2. **Crowbar Circuit**: For power line manipulation
3. **SWD Interface**: For debugging ARM-based targets
4. **AVRISP**: For programming AVR microcontrollers
5. **Analog Monitoring**: For capturing and analyzing signals
6. **FPGA**: Programmable logic for custom hardware implementations

## Voltage Glitching

Voltage glitching is a technique where you briefly disrupt the power supply to a target device, potentially causing it to skip instructions or bypass security checks.

### Basic Glitching

1. Connect your target device to the badge's glitching output
2. Configure the glitch parameters:
   ```
   glitch delay 100    # Set delay in microseconds
   glitch duration 10  # Set duration in microseconds
   ```

3. Check the current settings:
   ```
   glitch status
   ```

4. Trigger the glitch:
   ```
   glitch trigger
   ```
   
   Or use the shortcut:
   ```
   g
   ```

### Advanced Glitching Workflow

For systematic glitch testing:

1. Set initial parameters:
   ```
   glitch delay 50     # Start with 50µs delay
   glitch duration 5   # Use 5µs duration
   ```

2. Test the glitch:
   ```
   g                   # Trigger glitch
   ```

3. Adjust parameters and repeat:
   ```
   glitch delay 60     # Try different delay
   g                   # Test again
   ```

4. Monitor target response via UART or other interfaces to determine successful parameters.

## Crowbar Circuit

The crowbar circuit allows you to briefly short power lines, creating a different type of power disruption.

### Basic Crowbar Usage

1. Connect your target to the crowbar output
2. Configure the crowbar:
   ```
   crowbar delay 100      # Set delay in microseconds
   crowbar duration 5     # Set duration in microseconds
   ```

3. Check the current settings:
   ```
   crowbar status
   ```

4. Trigger the crowbar:
   ```
   crowbar trigger
   ```
   
   Or use the shortcut:
   ```
   c
   ```

## SWD Debugging

The badge can function as an SWD (Serial Wire Debug) adapter for ARM Cortex-M based devices.

### Connecting to a Target

1. Connect the badge to your target:
   - SWDIO → Target SWDIO
   - SWDCLK → Target SWDCLK
   - GND → Target GND

2. Reset the SWD interface:
   ```
   swd reset
   ```

3. Read target ID code:
   ```
   swd idcode
   ```

### Basic SWD Operations

Read data from SWD:
```
swd read 4    # Read 4 bytes
```

Write data to SWD:
```
swd write 0x01 0x02 0x03 0x04    # Write hex bytes
```

### Using with CMSIS-DAP

For more advanced debugging, switch to DAP mode:
```
usb mode dap
```

Then use tools like pyOCD, OpenOCD, or ARM Keil to debug your target.

## AVR Programming (AVRISP)

The badge can program AVR microcontrollers using the standard ISP protocol.

### Standard AVRISP (Fixed Pins)

1. Connect the badge to your AVR using the fixed pin assignments:
   - MOSI → AVR MOSI
   - MISO → AVR MISO
   - SCK → AVR SCK
   - RESET → AVR RESET
   - GND → AVR GND
   - VCC → AVR VCC (optional)

2. initialise the AVRISP interface:
   ```
   avrisp init
   ```

3. Detect the connected AVR:
   ```
   avrisp detect
   ```

### Programming with Standard AVRISP

Program the flash:
```
avrisp program firmware.hex
```

Verify the flash:
```
avrisp verify firmware.hex
```

Read/write fuses:
```
avrisp fuses read
avrisp fuses write
```

Erase the chip:
```
avrisp erase
```

Run AVRISP service on CDC1:
```
avrisp run
```

### Configurable AVRISP2/AB

For custom pin assignments:

1. initialise with custom pins:
   ```
   avrisp2 init pins sck=2 miso=3 mosi=4 reset=5 power=6
   ```

2. Or initialise with mode:
   ```
   avrisp2 init spi
   avrisp2 init bitbang
   ```

3. Use AB commands (shortcut):
   ```
   ab detect
   ab erase
   ab fuses read
   ```

## Analog Monitoring

The badge includes analog monitoring capabilities for capturing and analyzing signals.

### Basic ADC Reading

Read voltage measurement:
```
adc voltage
```

Read current measurement:
```
adc current
```

Read all ADC channels:
```
adc all
```

### Continuous Monitoring

Start ADC streaming:
```
adc_stream start
```

This streams ADC readings to the CDC2 interface in Normal USB mode.

Check streaming status:
```
adc_stream status
```

Stop ADC streaming:
```
adc_stream stop
```

### Trigger-Based Capture

Capture ADC data when a trigger condition is met:
```
adc capture channel=0 trigger=rising threshold=2.5 samples=1000 pretrigger=100
```

This captures 1000 samples when channel 0 crosses 2.5V with a rising edge, including 100 samples before the trigger.

## FPGA Programming

The badge includes an ICE40 FPGA that can be programmed for custom hardware implementations.

### Loading a Bitstream

Load a bitstream from a file:
```
ice load custom_design.bin
```

### FPGA Control

Start the FPGA:
```
ice start
```

Stop the FPGA:
```
ice stop
```

Check FPGA status:
```
ice status
```

### FPGA Communication

Send data to the FPGA:
```
ice write 0x01 0x02 0x03 0x04
```

Read data from the FPGA:
```
ice read 4    # Read 4 bytes
```

## Combining Techniques

The real power of the badge comes from combining different techniques.

### Example: Glitch-Based Password Bypass

1. Connect to target UART:
   ```
   uart setup baud=115200 tx=0 rx=1
   ```

2. Set up the glitcher:
   ```
   glitch setup width=10 delay=100 trigger=uart pattern="Password:"
   ```

3. Arm the glitcher:
   ```
   glitch arm
   ```

4. Send login command to target:
   ```
   uart send "login admin"
   ```

The glitcher will automatically trigger when the target prompts for a password.

### Example: SWD Memory Manipulation During Operation

1. Connect to target via SWD
2. Monitor a memory location:
   ```
   swd watch 0x20000100
   ```

3. Set up a trigger to modify memory when a specific value is detected:
   ```
   swd trigger addr=0x20000100 value=0x01 action="write 0x20000104 0x12345678"
   ```

This will automatically write to address 0x20000104 when the value at 0x20000100 becomes 0x01.

## Safety Precautions

When using the hardware hacking features:

1. **Always check voltage levels** before connecting to targets
2. **Start with conservative glitch parameters** to avoid damaging targets
3. **Use current limiting** when possible
4. **Be careful with the crowbar circuit** as it can draw significant current
5. **Disconnect sensitive equipment** when experimenting with new techniques

## Troubleshooting

### Glitcher Not Working

1. Check connections to the target
2. Verify the glitch parameters are appropriate for your target
3. Ensure the target is powered correctly
4. Try different timing parameters

### SWD Connection Issues

1. Check the SWD connections
2. Verify the target is powered
3. Try a slower SWD clock speed:
   ```
   swd setup speed=100
   ```
4. Make sure the target is not in a locked state

### AVRISP Problems

1. Check connections
2. Verify the clock speed is appropriate:
   ```
   avrisp setup speed=100
   ```
3. Make sure the target AVR is powered
4. Try resetting the target before operations

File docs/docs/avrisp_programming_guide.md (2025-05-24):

# LayerOne 2025 GLiTCh BadgE - AVRISP Programming Guide

## Introduction

The LayerOne 2025 GLiTCh BadgE includes a powerful AVRISP (AVR In-System Programming) capability that allows you to program AVR microcontrollers directly from the badge. This guide explains how to use this feature for programming, reading, and verifying AVR chips.

## What is AVRISP?

AVRISP (AVR In-System Programming) is a protocol developed by Atmel (now Microchip) for programming AVR microcontrollers while they are installed in a circuit. The badge implements this protocol, allowing it to function as an AVRISP programmer compatible with tools like AVRDUDE.

## Supported AVR Chips

The badge has built-in support for several common AVR microcontrollers:

| Chip | Flash Size | Page Size | Signature Bytes |
|---|---|---|---|
| ATtiny13A | 1KB | 32 bytes | 0x1E, 0x90, 0x07 |
| ATtiny85 | 8KB | 64 bytes | 0x1E, 0x93, 0x0B |
| ATmega328P | 32KB | 128 bytes | 0x1E, 0x95, 0x0F |
| ATmega328PB | 32KB | 128 bytes | 0x1E, 0x95, 0x16 |
| ATmega644PA | 64KB | 256 bytes | 0x1E, 0x96, 0x0A |
| ATmega2560 | 256KB | 256 bytes | 0x1E, 0x98, 0x01 |

## Hardware Setup

### Connecting to an AVR Chip

To program an AVR microcontroller, you need to connect the badge to the target chip using the following pins:

1. **MOSI** (Master Out Slave In): Connect to the target's MOSI pin
2. **MISO** (Master In Slave Out): Connect to the target's MISO pin
3. **SCK** (Serial Clock): Connect to the target's SCK pin
4. **RESET**: Connect to the target's RESET pin
5. **GND** (Ground): Connect to the target's GND
6. **VCC** (Optional): Connect to the target's VCC if you want to power the target from the badge

### Connection Diagram

```
┌─────────┐           ┌─────────┐
│         │  MOSI     │         │
│  Badge  ├───────────┤   AVR   │
│         │           │         │
│         │  MISO     │         │
│         ├───────────┤         │
│         │           │         │
│         │  SCK      │         │
│         ├───────────┤         │
│         │           │         │
│         │  RESET    │         │
│         ├───────────┤         │
│         │           │         │
│         │  GND      │         │
│         ├───────────┤         │
│         │           │         │
└─────────┘           └─────────┘
```

### SPI Clock Speed

The badge supports two SPI clock speeds for programming:
- **Slow Clock**: 100 kHz (for slower AVR chips or longer wires)
- **Fast Clock**: 1 MHz (for faster programming with most chips)

## Using the CLI Interface

The badge's CLI provides several commands for AVR programming operations:

### Basic AVRISP Commands

#### Initializing the AVRISP Interface

```
avrisp init
```

This command initializes the AVRISP interface with default settings.

#### Identifying the Connected Chip

```
avrisp identify
```

This command reads the signature bytes from the connected AVR chip and attempts to identify it based on the signature.

Example output:
```
Reading signature...
Signature: 0x1E 0x95 0x0F
Identified chip: ATmega328P
Flash size: 32KB
Page size: 128 bytes
```

### Programming Commands

#### Reading Flash Memory

```
avrisp read flash [filename]
```

This command reads the entire flash memory from the AVR chip and optionally saves it to a file.

#### Programming Flash Memory

```
avrisp program [filename]
```

This command programs the AVR chip with the contents of the specified HEX file.

Example:
```
avrisp program blink.hex
```

#### Verifying Flash Memory

```
avrisp verify [filename]
```

This command verifies that the contents of the AVR chip's flash memory match the specified HEX file.

### Fuse Operations

AVR chips use fuse bytes to configure various hardware settings. The badge provides commands to read and write these fuses.

#### Reading Fuses

```
avrisp read fuses
```

This command reads all fuse bytes (low, high, extended, and lock bits) from the AVR chip.

Example output:
```
Low fuse: 0xFF
High fuse: 0xD9
Extended fuse: 0xFF
Lock bits: 0xFF
```

#### Writing Fuses

```
avrisp write lfuse [value]
avrisp write hfuse [value]
avrisp write efuse [value]
avrisp write lock [value]
```

These commands write values to the specified fuse bytes.

Example:
```
avrisp write lfuse 0xFF
avrisp write hfuse 0xD9
avrisp write efuse 0xFF
```

### Advanced Commands

#### Erasing the Chip

```
avrisp erase
```

This command performs a chip erase, clearing all flash memory, EEPROM, and (in some cases) fuse bytes.

#### Reading EEPROM

```
avrisp read eeprom [filename]
```

This command reads the EEPROM memory from the AVR chip and optionally saves it to a file.

#### Writing EEPROM

```
avrisp write eeprom [filename]
```

This command writes data to the EEPROM memory of the AVR chip from the specified file.

## Using with AVRDUDE

The badge can function as an AVRISP programmer compatible with AVRDUDE, a popular command-line tool for programming AVR microcontrollers.

### Setting Up AVRDUDE

1. Connect the badge to your computer
2. Switch to AVRISP mode:
   ```
   usb mode avrisp
   ```
3. Note the serial port assigned to the badge (e.g., /dev/ttyACM0, COM3)

### AVRDUDE Commands

#### Reading the Chip Signature

```
avrdude -c avrisp -P [port] -p m328p
```

Replace `[port]` with your serial port and `m328p` with your target chip.

#### Programming a HEX File

```
avrdude -c avrisp -P [port] -p m328p -U flash:w:blink.hex:i
```

#### Reading Fuses

```
avrdude -c avrisp -P [port] -p m328p -U lfuse:r:-:h -U hfuse:r:-:h -U efuse:r:-:h
```

#### Writing Fuses

```
avrdude -c avrisp -P [port] -p m328p -U lfuse:w:0xFF:m -U hfuse:w:0xD9:m
```

## Programming Examples

### Example 1: Programming an Arduino Bootloader

To program an ATmega328P with the Arduino bootloader:

1. Connect the badge to the ATmega328P
2. Initialize the AVRISP interface:
   ```
   avrisp init
   ```
3. Identify the chip:
   ```
   avrisp identify
   ```
4. Erase the chip:
   ```
   avrisp erase
   ```
5. Program the bootloader:
   ```
   avrisp program arduino_bootloader.hex
   ```
6. Set the fuses for the Arduino:
   ```
   avrisp write lfuse 0xFF
   avrisp write hfuse 0xD6
   avrisp write efuse 0xFD
   ```
7. Verify the programming:
   ```
   avrisp verify arduino_bootloader.hex
   ```

### Example 2: Reading and Backing Up an Existing Chip

To read and back up the contents of an existing AVR chip:

1. Connect the badge to the AVR chip
2. Initialize the AVRISP interface:
   ```
   avrisp init
   ```
3. Identify the chip:
   ```
   avrisp identify
   ```
4. Read and save the flash memory:
   ```
   avrisp read flash backup.hex
   ```
5. Read and save the fuses:
   ```
   avrisp read fuses
   ```
   (Note the values for future reference)
6. Read and save the EEPROM (if needed):
   ```
   avrisp read eeprom backup.eep
   ```

## Troubleshooting

### Common Issues

#### Cannot Identify Chip

If the badge cannot identify the chip:

1. Check your connections, especially RESET, MOSI, MISO, and SCK
2. Ensure the chip is powered (VCC and GND)
3. Try a slower clock speed:
   ```
   avrisp init slow
   ```
4. Check if the chip is in a deep sleep mode or has fuses set that disable programming

#### Programming Fails

If programming fails:

1. Verify the chip is properly connected
2. Ensure the chip is not write-protected (check lock bits)
3. Try erasing the chip first:
   ```
   avrisp erase
   ```
4. Verify the HEX file is valid and appropriate for your chip
5. Check if the chip has enough memory for your program

#### Fuse Programming Warnings

Be careful when programming fuses! Incorrect fuse settings can make the chip unprogrammable through normal means. Common dangerous settings include:

- Disabling the RESET pin
- Setting incorrect clock sources
- Enabling brown-out detection at too high a voltage

If you're unsure about fuse values, consult the datasheet for your specific AVR chip or use an online fuse calculator.

## Advanced Usage

### High-Voltage Programming

Some AVR chips that have been "bricked" by incorrect fuse settings may require high-voltage programming to recover. The badge does not support high-voltage programming directly, but you can use it in conjunction with a high-voltage adapter.

### Clock Considerations

When programming chips with non-standard clock configurations:

1. If the chip uses an external crystal, ensure it's connected
2. If the chip uses an internal RC oscillator, be aware of its frequency
3. For chips running at very low clock speeds, use the slow programming clock

## Conclusion

The AVRISP functionality of the LayerOne 2025 GLiTCh BadgE provides a powerful and flexible way to program AVR microcontrollers. Whether you're programming a new chip, recovering a bricked device, or just experimenting with AVR development, the badge offers all the tools you need for successful AVR programming.

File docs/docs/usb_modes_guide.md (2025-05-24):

# LayerOne 2025 GLiTCh BadgE - USB Modes Guide

## Introduction

The LayerOne 2025 GLiTCh BadgE supports multiple USB modes that change how it appears to your computer and what functionality is available. This guide explains the different USB modes, how to switch between them, and how to use each mode effectively.

## USB Mode Overview

The badge supports three primary USB modes:

1. **Normal Mode**: Provides multiple interfaces for general use
2. **DAP Mode**: Provides debugging capabilities
3. **DFU Mode**: Allows firmware updates

## Switching Between Modes

You can switch between USB modes using the CLI command:

```
usb mode [normal|dap|dfu]
```

For example:
- `usb mode normal` - Switch to Normal mode
- `usb mode dap` - Switch to DAP mode
- `usb mode dfu` - Switch to DFU mode

After switching modes, the badge will reset and re-enumerate as a different USB device. Your computer may show a notification about a new device being connected.

## Normal Mode

### Description

Normal mode is the default mode and provides the most comprehensive set of interfaces for general use.

### Interfaces

In Normal mode, the badge presents itself as:

1. **CDC0 (Serial Port)**: Command Line Interface (CLI)
   - Use this to send commands to the badge
   - Connect using `cli_terminal.py` or any serial terminal at 115200 baud

2. **CDC1 (Serial Port)**: Debug Interface
   - Provides debug output from the badge
   - Connect using any serial terminal at 115200 baud

3. **CDC2 (Serial Port)**: ADC Stream Interface
   - Receives streaming ADC data when enabled
   - Enable with the command `adc_stream start`
   - Connect using any serial terminal at 115200 baud

4. **MSC (Mass Storage)**: Flash Storage
   - Appears as a USB drive on your computer
   - Can be used to transfer files to/from the badge
   - Contains documentation and example files

### Use Cases

- General badge interaction and control
- Accessing the file system
- Monitoring debug output
- Capturing analog data streams

## DAP Mode (CMSIS-DAP)

### Description

DAP mode turns the badge into a CMSIS-DAP debug probe, which can be used to debug the badge itself or external targets.

### Interfaces

In DAP mode, the badge presents itself as:

1. **CMSIS-DAP Interface**: Debug Probe
   - Appears as a CMSIS-DAP compatible debug probe
   - Can be used with tools like pyOCD, OpenOCD, or ARM Keil

2. **CDC0 (Serial Port)**: Command Line Interface (CLI)
   - Still available for sending commands to the badge
   - Connect using `cli_terminal.py` or any serial terminal at 115200 baud

### Use Cases

- Debugging the badge's RP2040 microcontroller
- Debugging external ARM Cortex-M based targets
- Programming flash memory on the badge or external targets
- Hardware hacking and security research

### Using with pyOCD

To use the badge as a CMSIS-DAP probe with pyOCD:

1. Install pyOCD:
   ```
   pip install pyocd
   ```

2. List connected probes:
   ```
   pyocd list
   ```

3. Connect to a target:
   ```
   pyocd commander -t rp2040 -u [serial_number]
   ```
   Where `[serial_number]` is the serial number of your badge (e.g., `00000000000000032`)

4. Example commands in pyOCD:
   ```
   info        # Show target information
   reg         # Show registers
   mem read 0x10000000 16    # Read 16 bytes from address 0x10000000
   mem write 0x20000000 0x12345678    # Write to memory
   ```

## DFU Mode (Device Firmware Update)

### Description

DFU mode allows you to update the firmware on the badge using standard DFU tools.

### Interfaces

In DFU mode, the badge presents itself as:

1. **DFU Interface**: Firmware Update Interface
   - Appears as a standard USB DFU device
   - Can be used with tools like dfu-util

2. **CDC0 (Serial Port)**: Command Line Interface (CLI)
   - Still available for sending commands to the badge
   - Connect using `cli_terminal.py` or any serial terminal at 115200 baud

### Use Cases

- Updating the badge firmware
- Recovering from firmware issues
- Installing custom firmware

### Using with dfu-util

To update firmware using dfu-util:

1. Install dfu-util:
   - On macOS: `brew install dfu-util`
   - On Linux: `sudo apt install dfu-util`
   - On Windows: Download from [dfu-util.sourceforge.net](http://dfu-util.sourceforge.net/)

2. List connected DFU devices:
   ```
   dfu-util -l
   ```

3. Flash new firmware:
   ```
   dfu-util -d 1209:2025 -a 0 -D firmware.bin
   ```
   Where `firmware.bin` is your firmware file

## Troubleshooting

### Device Not Recognized After Mode Switch

If your computer doesn't recognize the badge after switching modes:

1. Wait at least 60 seconds for the device to re-enumerate
2. Unplug and replug the badge
3. Try a different USB port or cable
4. Check if the device appears in Device Manager (Windows), System Information (macOS), or `lsusb` (Linux)

### Can't Connect to Serial Port

If you can't connect to the serial port:

1. Make sure you're using the correct port name
2. Check if another program is using the port
3. Try a different USB port
4. Restart the badge

### CMSIS-DAP Not Working

If the CMSIS-DAP interface isn't working:

1. Make sure you're in DAP mode (`usb mode dap`)
2. Check if the device appears in pyOCD (`pyocd list`)
3. Try updating pyOCD to the latest version
4. Check your target connections if debugging an external device

## Advanced: USB Descriptors

The badge uses the following USB identifiers:

- **Normal Mode**:
  - VID:PID: 0x1209:0x2025
  - Manufacturer: "NullSpaceLabs"
  - Product: "GLiTCh BadgE 2025"

- **DAP Mode**:
  - VID:PID: 0x0D28:0x2488 (Standard CMSIS-DAP VID:PID)
  - Manufacturer: "NullSpaceLabs"
  - Product: "CMSIS-DAP"

- **DFU Mode**:
  - VID:PID: 0x1209:0x2025
  - Manufacturer: "NullSpaceLabs"
  - Product: "GLiTCh BadgE 2025 DFU"

## Testing USB Modes

A comprehensive test script is provided to verify all USB modes:

```
python3 test_usb_modes.py
```

This script will:
1. Test Normal mode functionality
2. Switch to DAP mode and test CMSIS-DAP functionality
3. Switch to DFU mode and verify DFU interface
4. Switch back to Normal mode

You can skip specific tests with command-line options:
```
python3 test_usb_modes.py --skip-build --skip-dfu

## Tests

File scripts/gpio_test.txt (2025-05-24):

# gpio test script
print "Testing GPIO pins..."

# test output pins
pin 2 out
pin 3 out

loop 5
    pin 2 high
    pin 3 low
    sleep 200ms
    pin 2 low  
    pin 3 high
    sleep 200ms
endloop

print "GPIO test complete"

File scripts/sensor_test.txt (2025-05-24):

# sensor test script
adc init 0
adc init 1
adc temp_init

loop 10
    adc 0 -> pot
    adc 1 -> light
    adc temp -> temp_raw
    
    print "Pot: " pot " Light: " light " Temp: " temp_raw
    sleep 500ms
endloop

print "Sensor test complete"

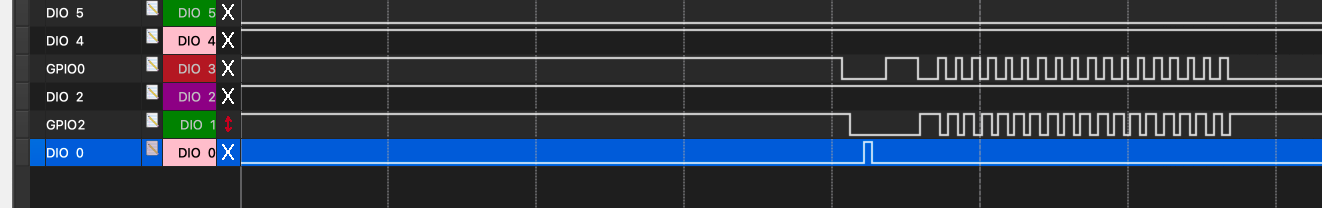
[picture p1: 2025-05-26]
scriptTestrun.png

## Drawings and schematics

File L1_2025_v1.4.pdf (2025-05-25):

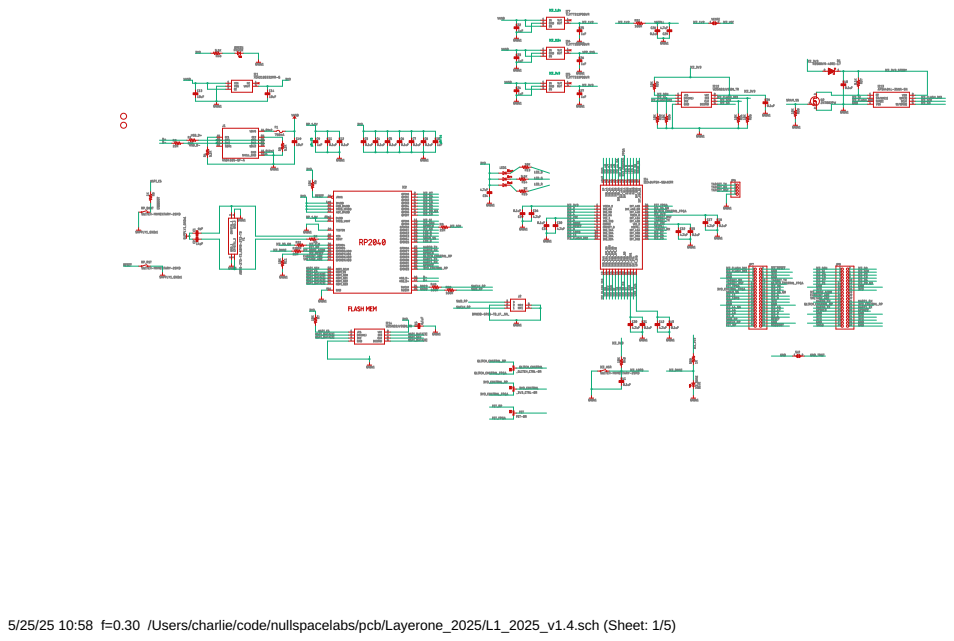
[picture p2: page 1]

5/25/25 10:58 f=0.30 /Users/charlie/code/nullspacelabs/pcb/Layerone_2025/L1_2025_v1.4.sch (Sheet: 1/5)

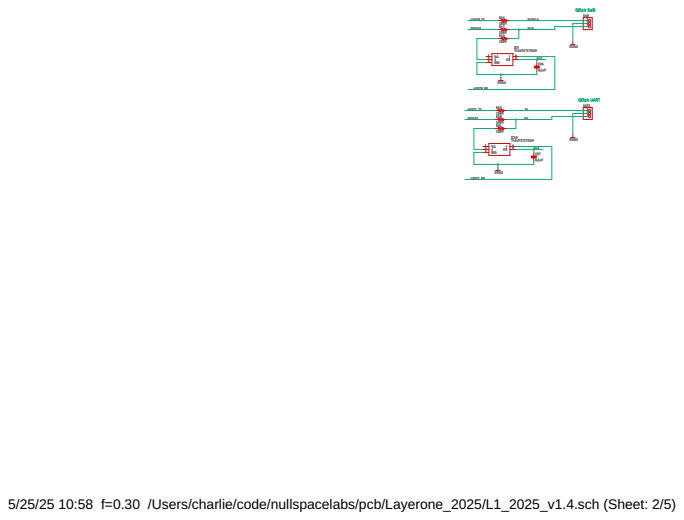
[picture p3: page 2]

5/25/25 10:58 f=0.30 /Users/charlie/code/nullspacelabs/pcb/Layerone_2025/L1_2025_v1.4.sch (Sheet: 2/5)

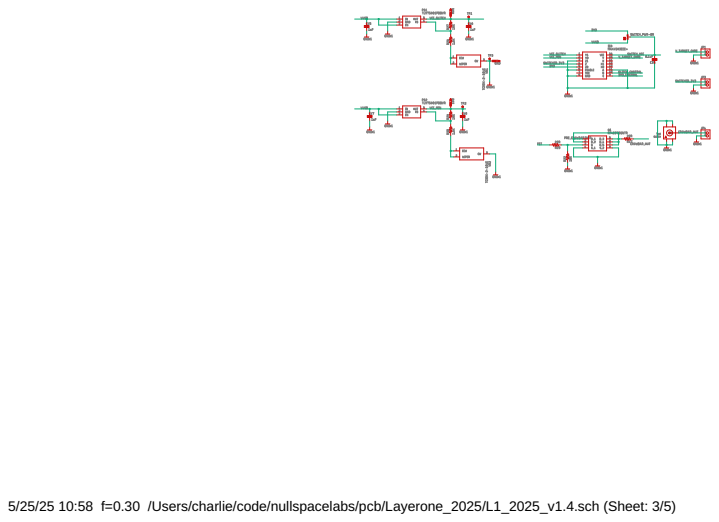
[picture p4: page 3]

5/25/25 10:58 f=0.30 /Users/charlie/code/nullspacelabs/pcb/Layerone_2025/L1_2025_v1.4.sch (Sheet: 3/5)

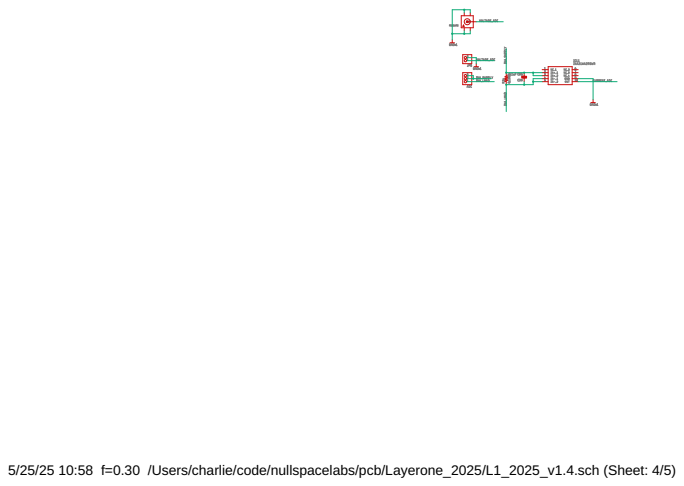
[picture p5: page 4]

5/25/25 10:58 f=0.30 /Users/charlie/code/nullspacelabs/pcb/Layerone_2025/L1_2025_v1.4.sch (Sheet: 4/5)

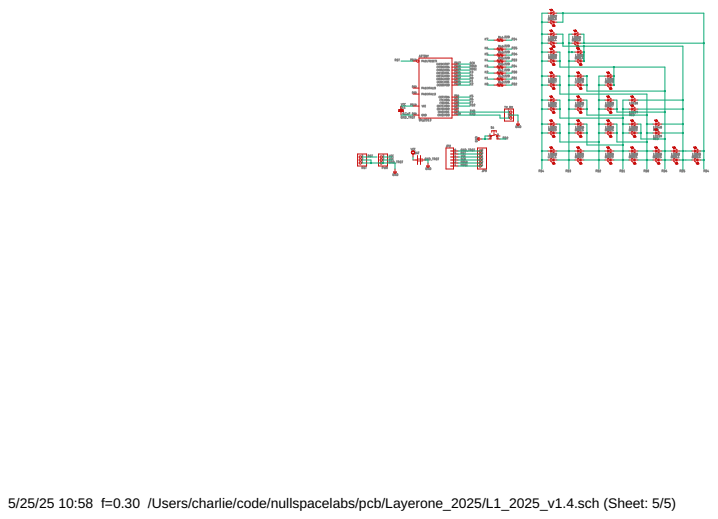
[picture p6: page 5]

5/25/25 10:58 f=0.30 /Users/charlie/code/nullspacelabs/pcb/Layerone_2025/L1_2025_v1.4.sch (Sheet: 5/5)

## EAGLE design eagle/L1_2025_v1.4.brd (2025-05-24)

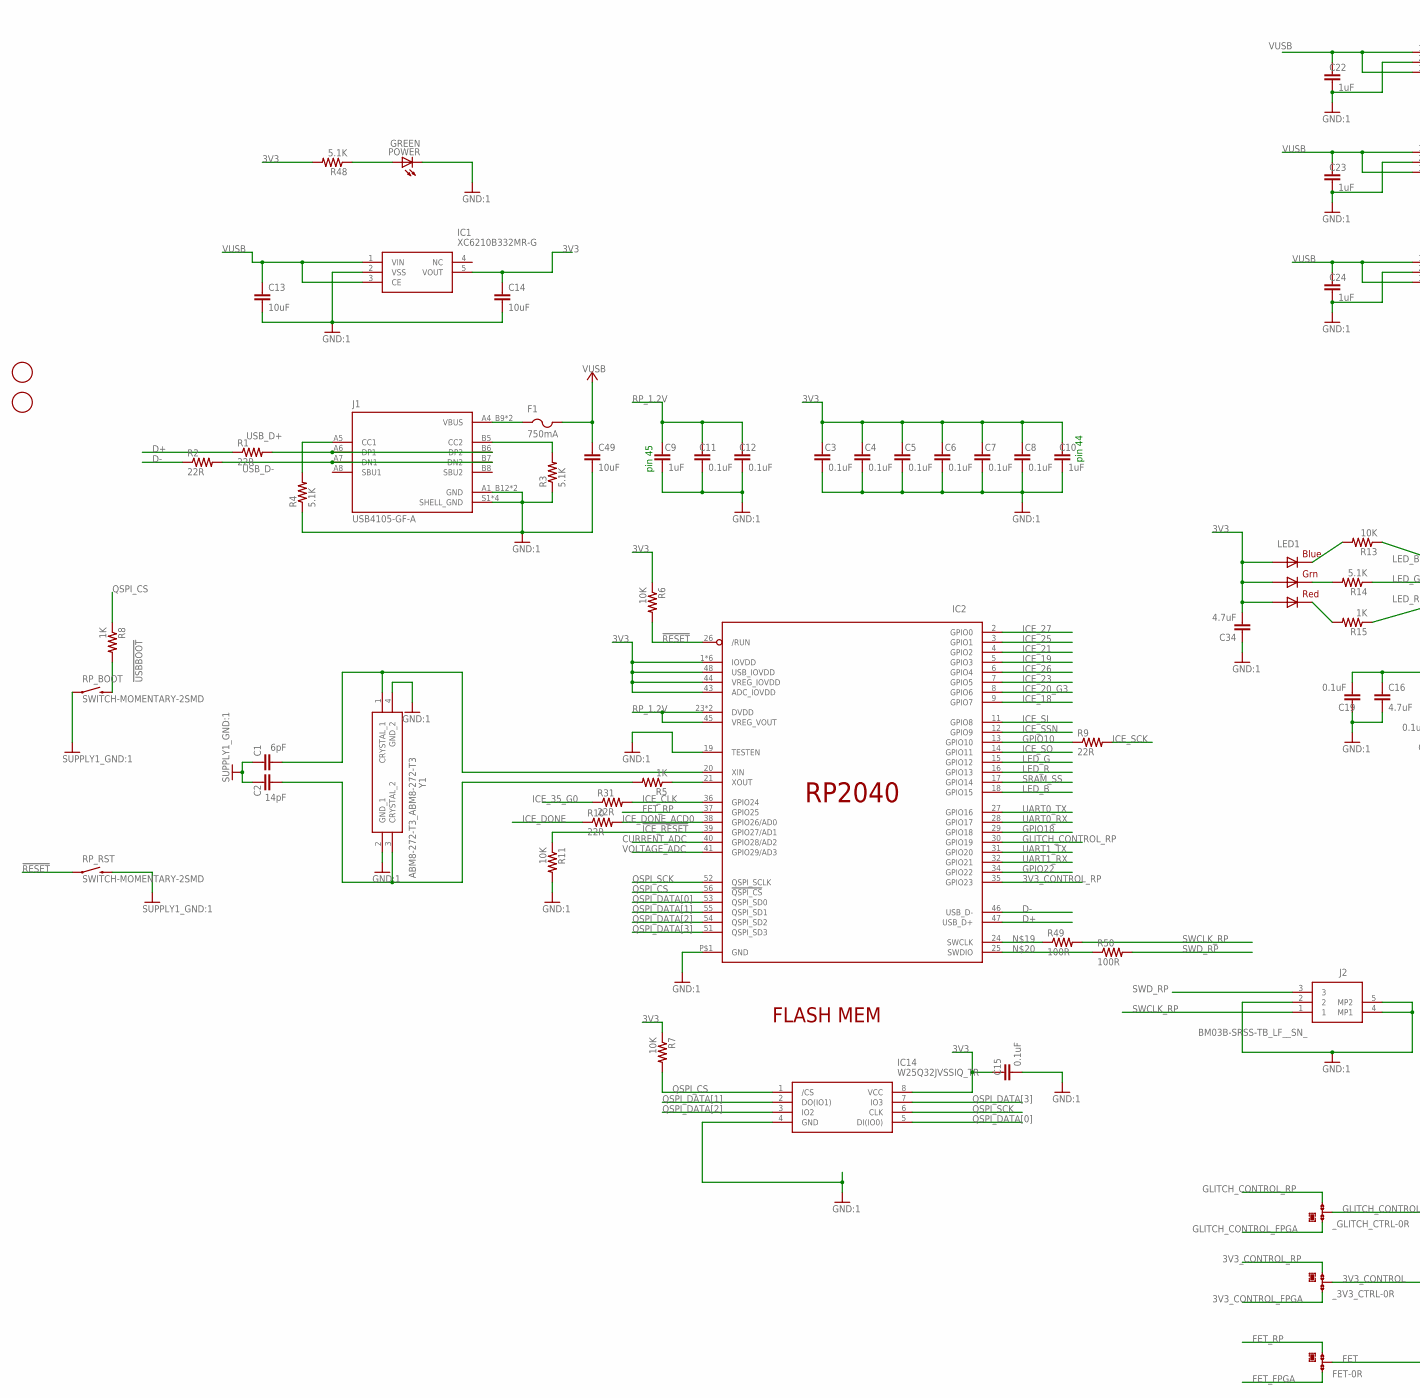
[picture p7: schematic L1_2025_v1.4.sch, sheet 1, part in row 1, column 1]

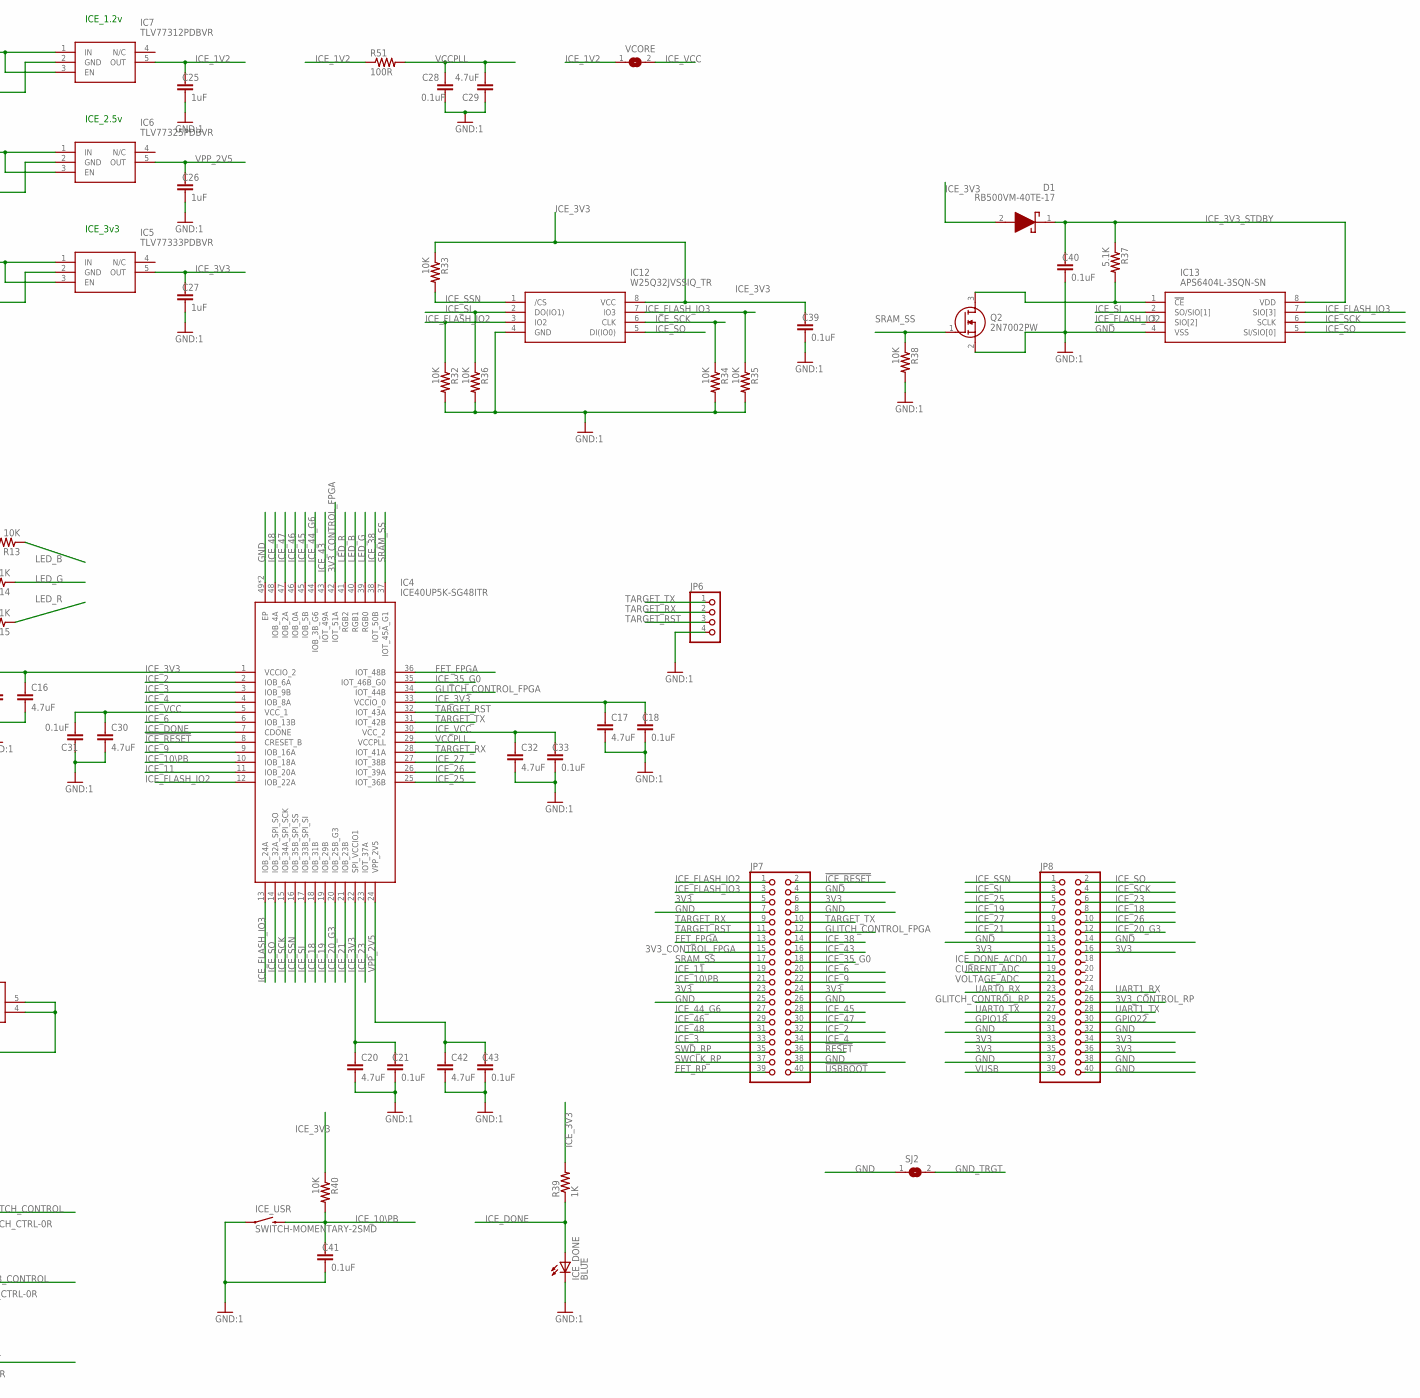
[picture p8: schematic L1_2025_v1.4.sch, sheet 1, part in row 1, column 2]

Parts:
AFID1, AFID2: FIDUCIAL; FIDUCIAL_1MM
C1: 6pF; 0402-CAP
C2: 14pF; 0402-CAP
C3, C4, C5, C6, C7, C8, C11, C12, C15, C18, C19, C21, C28, C31, C33, C39, C40, C41, C43: 0.1uF; 0402-CAP
C9, C10, C22, C23, C24, C25, C26, C27: 1uF; 0402-CAP
C13, C14, C49: 10uF; 0603-CAP
C16, C17, C20, C29, C30, C32, C34, C42: 4.7uF; 0603-CAP
D1: RB500VM-40TE-17; RB500VM40TE17
F1: 750mA; R1206
FET: 0R-JUMPC; C0R-JMP
IC1: XC6210B332MR-G; SOT95P280X130-5N
IC2: ADAFRUIT_MICRO_RP2040_QFN56; ADAFRUIT_MICRO_QFN56_7MM_REDUCEDEPAD
IC4: ICE40UP5K-SG48ITR; QFN50P700X700X100-49N
IC5: TLV77333PDBVR; SOT95P280X145-5N
IC6: TLV77325PDBVR; SOT95P280X145-5N
IC7: TLV77312PDBVR; SOT95P280X145-5N
IC12, IC14: W25Q32JVSSIQ_TR; SOIC127P790X216-8N
IC13: APS6404L-3SQN-SN; SOIC127P600X175-8N
ICE_DONE: BLUE; LED-1206
ICE_USR: SWITCH-MOMENTARY-2SMD; TACTILE_SWITCH_SMD
J1: USB4105-GF-A; GCT_USB4105-GF-A
J2: BM03B-SRSS-TB_LF__SN_; BM03BSRSSTBLFSN
JP6: PINHD-1X4; 1X04
JP7, JP8: PINHD-2X20-BIG; 2X20-BIG
LED1: RGBLED5050
POWER: GREEN; LED-1206
Q2: 2N7002PW; SOT65P210X110-3N
R1, R2, R9, R10, R31: 22R; 0402-RES:1
R3, R4, R14, R37, R48: 5.1K; 0402-RES:1
R5, R8, R15, R39: 1K; 0402-RES:1
R6, R7, R11, R13, R32, R33, R34, R35, R36, R38, R40: 10K; 0402-RES:1
R49, R50, R51: 100R; 0402-RES:1
RP_BOOT: SWITCH-MOMENTARY-2SMD; TACTILE_SWITCH_SMD
RP_RST: SWITCH-MOMENTARY-2SMD; TACTILE_SWITCH_SMD
SJ2: SJ
VCORE: SJ
Y1: ABM8-272-T3_ABM8-272-T3; ABM8-272-T3_ABM8272T3
_3V3_CTRL: 0R-JUMPC; C0R-JMP
_GLITCH_CTRL: 0R-JUMPC; C0R-JMP

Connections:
3V3: C3.2, C4.2, C5.2, C6.2, C7.2, C8.2, C10.2, C14.1, C15.2, C34.2, IC1.5 (VOUT), IC2.1 (IOVDD), IC2.10 (IOVDD), IC2.22 (IOVDD), IC2.33 (IOVDD), IC2.42 (IOVDD), IC2.43 (ADC_IOVDD), IC2.44 (VREG_IOVDD), IC2.48 (USB_IOVDD), IC2.49 (IOVDD), IC14.8 (VCC), JP7.5, JP7.6, JP7.23, JP7.24, JP8.15, JP8.16, JP8.33, JP8.34, JP8.35, JP8.36, LED1.1 (GREEN_A), LED1.2 (RED_A), LED1.3 (BLUE_A), R6.1, R7.1, R48.2; also elsewhere on the board
3V3_CONTROL: _3V3_CTRL.2; also elsewhere on the board
3V3_CONTROL_FPGA: IC4.42 (IOT_51A), JP7.15, _3V3_CTRL.3
3V3_CONTROL_RP: IC2.35 (GPIO23), JP8.26, _3V3_CTRL.1
!ICE_RESET: IC2.39 (GPIO27/AD1), IC4.8 (CRESET_B), JP7.2, R11.1
!RESET: IC2.26 (/RUN), JP7.36, R6.2, RP_RST.1
!USBBOOT: JP7.40, R8.2, RP_BOOT.3 (2)
CURRENT_ADC: IC2.40 (GPIO28/AD2), JP8.19; also elsewhere on the board
D+: IC2.47 (USB_D+), R1.1
D-: IC2.46 (USB_D-), R2.1
FET: FET.2; also elsewhere on the board
FET_FPGA: FET.3, IC4.36 (IOT_48B), JP7.13
FET_RP: FET.1, IC2.37 (GPIO25), JP7.39
GLITCH_CONTROL: _GLITCH_CTRL.2; also elsewhere on the board
GLITCH_CONTROL_FPGA: IC4.34 (IOT_44B), JP7.12, _GLITCH_CTRL.3
GLITCH_CONTROL_RP: IC2.30 (GPIO19), JP8.25, _GLITCH_CTRL.1
GND: C1.1, C2.1, C3.1, C4.1, C5.1, C6.1, C7.1, C8.1, C9.1, C10.1, C11.1, C12.1, C13.2, C14.2, C15.1, C16.2, C17.2, C18.1, C19.2, C20.2, C21.1, C22.1, C23.1, C24.1, C25.1, C26.1, C27.1, C28.1, C29.1, C30.2, C31.2, C32.2, C33.1, C34.1, C39.1, C40.1, C41.1, C42.2, C43.1, C49.2, IC1.2 (VSS), IC2.19 (TESTEN), IC2.P$1 (GND), IC4.49 (EP), IC4.P$1 (EP), IC5.2 (GND), IC6.2 (GND), IC7.2 (GND), IC12.4 (GND), IC13.4 (VSS), IC14.4 (GND), ICE_DONE.C, ICE_USR.1, J1.A1_B12 (GND), J1.B1_A12 (GND), J1.S1 (SHELL_GND), J1.S2 (SHELL_GND), J1.S3 (SHELL_GND), J1.S4 (SHELL_GND), J2.2, J2.4 (MP1), J2.5 (MP2), JP6.4, JP7.4, JP7.7, JP7.8, JP7.25, JP7.26, JP7.38, JP8.13, JP8.14, JP8.31, JP8.32, JP8.37, JP8.38, JP8.40, POWER.C, Q2.2 (S), R3.1, R4.1, R11.2, R32.2, R34.2, R35.2, R36.2, R38.2, RP_BOOT.1, RP_RST.3 (2), SJ2.1, Y1.2 (GND_1), Y1.4 (GND_2); also elsewhere on the board
GND_TRGT: SJ2.2; also elsewhere on the board
GPIO10: IC2.13 (GPIO10), R9.1
GPIO18: IC2.29 (GPIO18), JP8.29; also elsewhere on the board
GPIO22: IC2.34 (GPIO22), JP8.30; also elsewhere on the board
ICE_1V2: C25.2, IC7.5 (OUT), R51.1, VCORE.1
ICE_2: IC4.2 (IOB_6A), JP7.32
ICE_3: IC4.3 (IOB_9B), JP7.33
ICE_3V3: C16.1, C17.1, C18.2, C19.1, C20.1, C21.2, C27.2, C39.2, D1.2 (A), IC4.1 (VCCIO_2), IC4.22 (SPI_VCCIO1), IC4.33 (VCCIO_0), IC5.5 (OUT), IC12.8 (VCC), R33.1, R39.2, R40.1
ICE_3V3_STDBY: C40.2, D1.1 (K), IC13.8 (VDD), R37.1
ICE_4: IC4.4 (IOB_8A), JP7.34
ICE_6: IC4.6 (IOB_13B), JP7.20
ICE_9: IC4.9 (IOB_16A), JP7.22
ICE_10\PB: C41.2, IC4.10 (IOB_18A), ICE_USR.3 (2), JP7.21, R40.2
ICE_11: IC4.11 (IOB_20A), JP7.19
ICE_18: IC2.9 (GPIO7), IC4.18 (IOB_31B), JP8.8
ICE_19: IC2.5 (GPIO3), IC4.19 (IOB_29B), JP8.7
ICE_20_G3: IC2.8 (GPIO6), IC4.20 (IOB_25B_G3), JP8.12
ICE_21: IC2.4 (GPIO2), IC4.21 (IOB_23B), JP8.11
ICE_23: IC2.7 (GPIO5), IC4.23 (IOT_37A), JP8.6
ICE_25: IC2.3 (GPIO1), IC4.25 (IOT_36B), JP8.5
ICE_26: IC2.6 (GPIO4), IC4.26 (IOT_39A), JP8.10
ICE_27: IC2.2 (GPIO0), IC4.27 (IOT_38B), JP8.9
ICE_35_G0: IC4.35 (IOT_46B_G0), JP7.18, R31.1
ICE_38: IC4.38 (IOT_50B), JP7.14
ICE_43: IC4.43 (IOT_49A), JP7.16
ICE_44_G6: IC4.44 (IOB_3B_G6), JP7.27
ICE_45: IC4.45 (IOB_5B), JP7.28
ICE_46: IC4.46 (IOB_0A), JP7.29
ICE_47: IC4.47 (IOB_2A), JP7.30
ICE_48: IC4.48 (IOB_4A), JP7.31
ICE_CLK: IC2.36 (GPIO24), R31.2
ICE_DONE: IC4.7 (CDONE), ICE_DONE.A, R10.1, R39.1
ICE_DONE_ACD0: IC2.38 (GPIO26/AD0), JP8.17, R10.2
ICE_FLASH_IO2: IC4.12 (IOB_22A), IC12.3 (IO2), IC13.3 (SIO[2]), JP7.1, R32.1
ICE_FLASH_IO3: IC4.13 (IOB_24A), IC12.7 (IO3), IC13.7 (SIO[3]), JP7.3, R35.1
ICE_SCK: IC4.15 (IOB_34A_SPI_SCK), IC12.6 (CLK), IC13.6 (SCLK), JP8.4, R9.2, R34.1
ICE_SI: IC2.11 (GPIO8), IC4.17 (IOB_33B_SPI_SI), IC12.2 (DO(IO1)), IC13.2 (SO/SIO[1]), JP8.3, R36.1
ICE_SO: IC2.14 (GPIO11), IC4.14 (IOB_32A_SPI_SO), IC12.5 (DI(IO0)), IC13.5 (SI/SIO[0]), JP8.2
ICE_SSN: IC2.12 (GPIO9), IC4.16 (IOB_35B_SPI_SS), IC12.1 (/CS), JP8.1, R33.2
ICE_VCC: C30.1, C31.1, C32.1, C33.2, IC4.5 (VCC_1), IC4.30 (VCC_2), VCORE.2
LED_B: IC2.18 (GPIO15), IC4.40 (RGB1), R13.1
LED_G: IC2.15 (GPIO12), IC4.39 (RGB0), R14.1
LED_R: IC2.16 (GPIO13), IC4.41 (RGB2), R15.1
unnamed: C2.2, R5.2, Y1.3 (CRYSTAL_2)
unnamed: IC2.21 (XOUT), R5.1
unnamed: C1.2, IC2.20 (XIN), Y1.1 (CRYSTAL_1)
unnamed: LED1.4 (BLUE_C), R13.2
unnamed: LED1.6 (GREEN_C), R14.2
unnamed: LED1.5 (RED_C), R15.2
unnamed: J1.A5 (CC1), R4.2
unnamed: J1.B5 (CC2), R3.2
unnamed: IC13.1 (!CE), Q2.3 (D), R37.2
unnamed: F1.1, J1.A4_B9 (VBUS), J1.B4_A9 (VBUS)
unnamed: POWER.A, R48.1
unnamed: IC2.24 (SWCLK), R49.1
unnamed: IC2.25 (SWDIO), R50.1
QSPI_CS: IC2.56 (!QSPI_CS), IC14.1 (/CS), R7.2, R8.1
QSPI_DATA[0]: IC2.53 (QSPI_SD0), IC14.5 (DI(IO0))
QSPI_DATA[1]: IC2.55 (QSPI_SD1), IC14.2 (DO(IO1))
QSPI_DATA[2]: IC2.54 (QSPI_SD2), IC14.3 (IO2)
QSPI_DATA[3]: IC2.51 (QSPI_SD3), IC14.7 (IO3)
QSPI_SCK: IC2.52 (QSPI_SCLK), IC14.6 (CLK)
RP_1.2V: C9.2, C11.2, C12.2, IC2.23 (DVDD), IC2.45 (VREG_VOUT), IC2.50 (DVDD)
SRAM_SS: IC2.17 (GPIO14), IC4.37 (IOT_45A_G1), JP7.17, Q2.1 (G), R38.1
SWCLK_RP: J2.1, JP7.37, R49.2
SWD_RP: J2.3, JP7.35, R50.2
TARGET_RST: IC4.32 (IOT_43A), JP6.3, JP7.11
TARGET_RX: IC4.28 (IOT_41A), JP6.2, JP7.9
TARGET_TX: IC4.31 (IOT_42B), JP6.1, JP7.10
UART0_RX: IC2.28 (GPIO17), JP8.23; also elsewhere on the board
UART0_TX: IC2.27 (GPIO16), JP8.27; also elsewhere on the board
UART1_RX: IC2.32 (GPIO21), JP8.24; also elsewhere on the board
UART1_TX: IC2.31 (GPIO20), JP8.28; also elsewhere on the board
USB_D+: J1.A6 (DP1), J1.B6 (DP2), R1.2
USB_D-: J1.A7 (DN1), J1.B7 (DN2), R2.2
VCCPLL: C28.2, C29.2, IC4.29 (VCCPLL), R51.2
VOLTAGE_ADC: IC2.41 (GPIO29/AD3), JP8.21; also elsewhere on the board
VPP_2V5: C26.2, C42.1, C43.2, IC4.24 (VPP_2V5), IC6.5 (OUT)
VUSB: C13.1, C22.2, C23.2, C24.2, C49.1, F1.2, IC1.1 (VIN), IC1.3 (CE), IC5.1 (IN), IC5.3 (EN), IC6.1 (IN), IC6.3 (EN), IC7.1 (IN), IC7.3 (EN), JP8.39; also elsewhere on the board

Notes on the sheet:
pin 45
pin 44
FLASH MEM
ICE_3v3
ICE_2.5v
ICE_1.2v

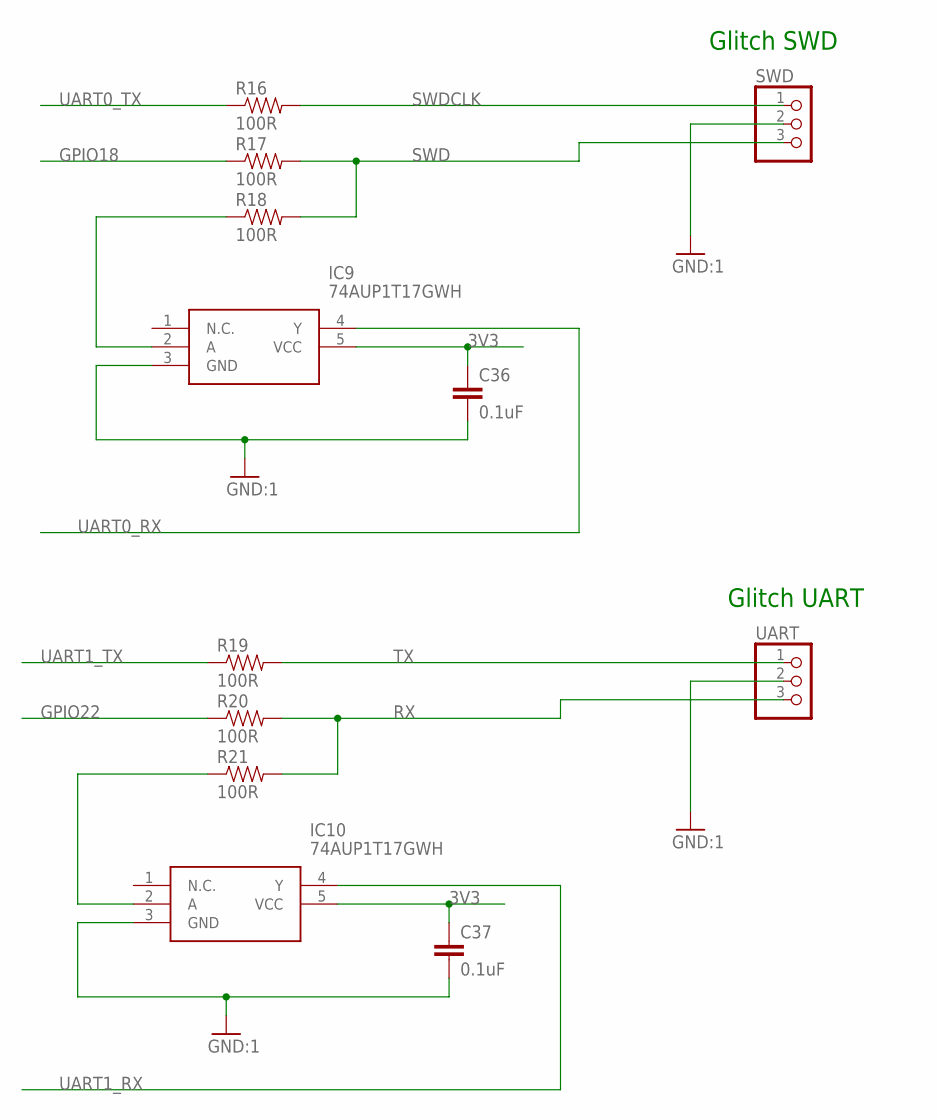
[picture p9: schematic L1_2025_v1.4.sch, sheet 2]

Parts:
C36, C37: 0.1uF; 0402-CAP
IC9, IC10: 74AUP1T17GWH; SOT65P212X110-5N
R16, R17, R18, R19, R20, R21: 100R; 0402-RES:1
SWD: PINHD-1X3; 1X03
UART: PINHD-1X3; 1X03

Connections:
3V3: C36.1, C37.1, IC9.5 (VCC), IC10.5 (VCC); also elsewhere on the board
GND: C36.2, C37.2, IC9.3 (GND), IC10.3 (GND), SWD.2, UART.2; also elsewhere on the board
GPIO18: R17.1; also elsewhere on the board
GPIO22: R20.1; also elsewhere on the board
unnamed: IC10.2 (A), R21.1
unnamed: IC9.2 (A), R18.1
RX: R20.2, R21.2, UART.3
SWD: R17.2, R18.2, SWD.3
SWDCLK: R16.2, SWD.1
TX: R19.2, UART.1
UART0_RX: IC9.4 (Y); also elsewhere on the board
UART0_TX: R16.1; also elsewhere on the board
UART1_RX: IC10.4 (Y); also elsewhere on the board
UART1_TX: R19.1; also elsewhere on the board

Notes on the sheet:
Glitch SWD
Glitch UART

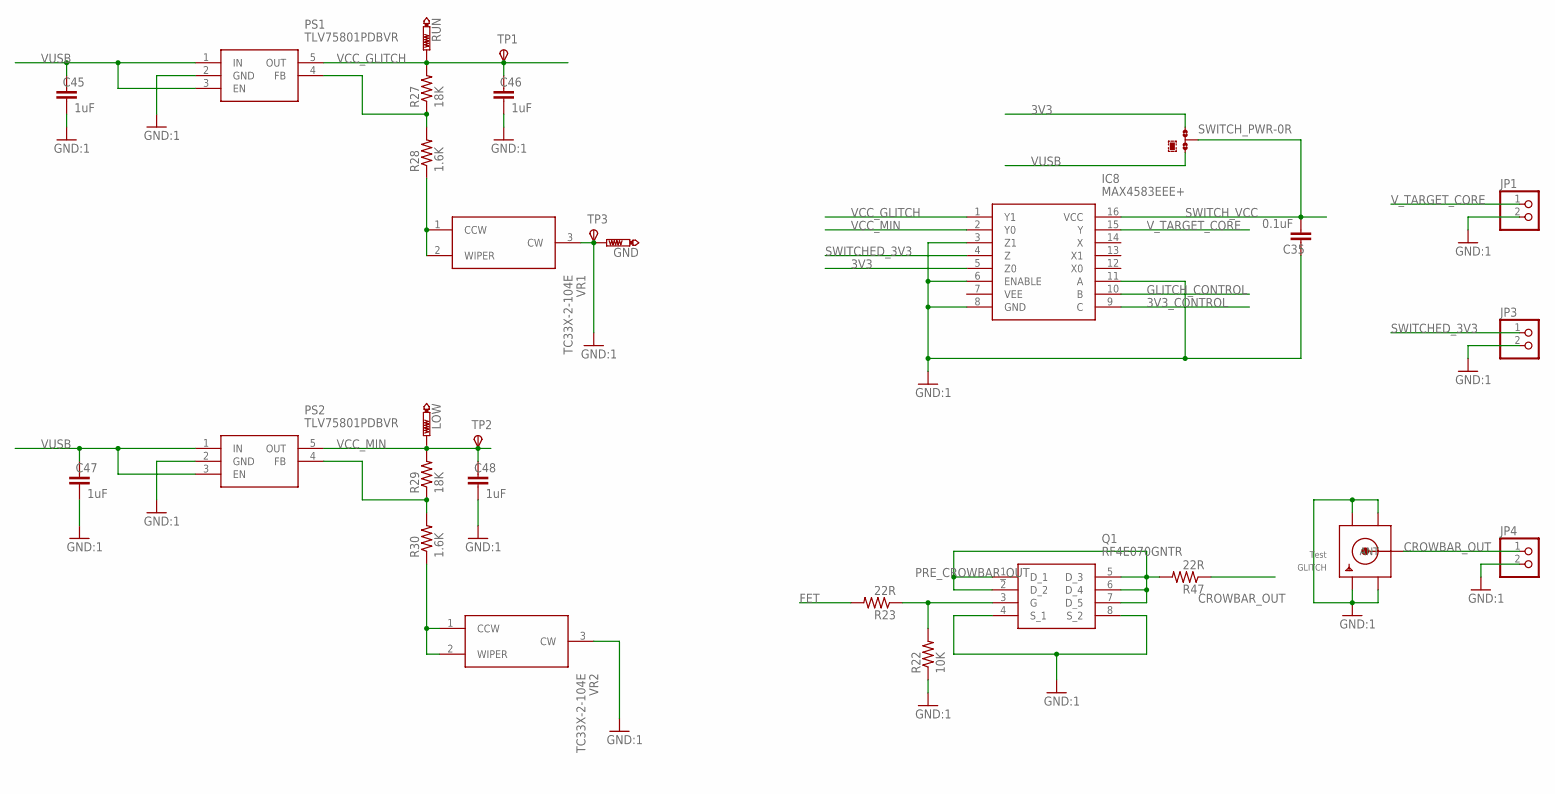
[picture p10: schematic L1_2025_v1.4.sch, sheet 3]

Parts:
C35: 0.1uF; 0402-CAP
C45, C46, C47, C48: 1uF; 0402-CAP
GLITCH: Test; SMA_EDGELAUNCH
GND: PTR1PAD1-13; P1-13
IC8: MAX4583EEE+; SOP64P602X175-16N
JP1, JP3, JP4: PINHD-1X2; 1X02
LOW: PTR1PAD1-13; P1-13
PS1, PS2: TLV75801PDBVR; SOT95P280X145-5N
Q1: RF4E070GNTR
R22: 10K; 0402-RES:1
R23, R47: 22R; 0402-RES:1
R27, R29: 18K; 0402-RES:1
R28, R30: 1.6K; 0402-RES:1
RUN: PTR1PAD1-13; P1-13
SWITCH_PWR: 0R-JUMPC; C0R-JMP
TP1, TP2, TP3: TESTPAD_TPSTP20R; TESTPAD_TP20R:1
VR1, VR2: TC33X-2-104E; TC33X2503E

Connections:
3V3: IC8.5 (Z0), SWITCH_PWR.1; also elsewhere on the board
3V3_CONTROL: IC8.9 (C); also elsewhere on the board
CROWBAR_OUT: GLITCH.P (ANT), JP4.1, R47.1
FET: R23.2; also elsewhere on the board
GLITCH_CONTROL: IC8.10 (B); also elsewhere on the board
GND: C35.2, C45.1, C46.1, C47.1, C48.1, GLITCH.GND@1 (GND4), GLITCH.GND@2 (GND3), GLITCH.GND@3 (GND2), GLITCH.GND@4 (GND1), GND.TP, IC8.3 (Z1), IC8.6 (ENABLE), IC8.8 (GND), IC8.11 (A), JP1.2, JP3.2, JP4.2, PS1.2 (GND), PS2.2 (GND), Q1.4 (S_1), Q1.8 (S_2), R22.1, TP3.TP, VR1.3 (CW), VR2.3 (CW); also elsewhere on the board
unnamed: PS1.4 (FB), R27.1, R28.2
unnamed: Q1.3 (G), R22.2, R23.1
unnamed: R28.1, VR1.1 (CCW), VR1.2 (WIPER)
unnamed: PS2.4 (FB), R29.1, R30.2
unnamed: R30.1, VR2.1 (CCW), VR2.2 (WIPER)
PRE_CROWBAR_OUT: Q1.1 (D_1), Q1.2 (D_2), Q1.5 (D_3), Q1.6 (D_4), Q1.7 (D_5), R47.2
SWITCHED_3V3: IC8.4 (Z), JP3.1
SWITCH_VCC: C35.1, IC8.16 (VCC), SWITCH_PWR.2
VCC_GLITCH: C46.2, IC8.1 (Y1), PS1.5 (OUT), R27.2, RUN.TP, TP1.TP
VCC_MIN: C48.2, IC8.2 (Y0), LOW.TP, PS2.5 (OUT), R29.2, TP2.TP
VUSB: C45.2, C47.2, PS1.1 (IN), PS1.3 (EN), PS2.1 (IN), PS2.3 (EN), SWITCH_PWR.3; also elsewhere on the board
V_TARGET_CORE: IC8.15 (Y), JP1.1

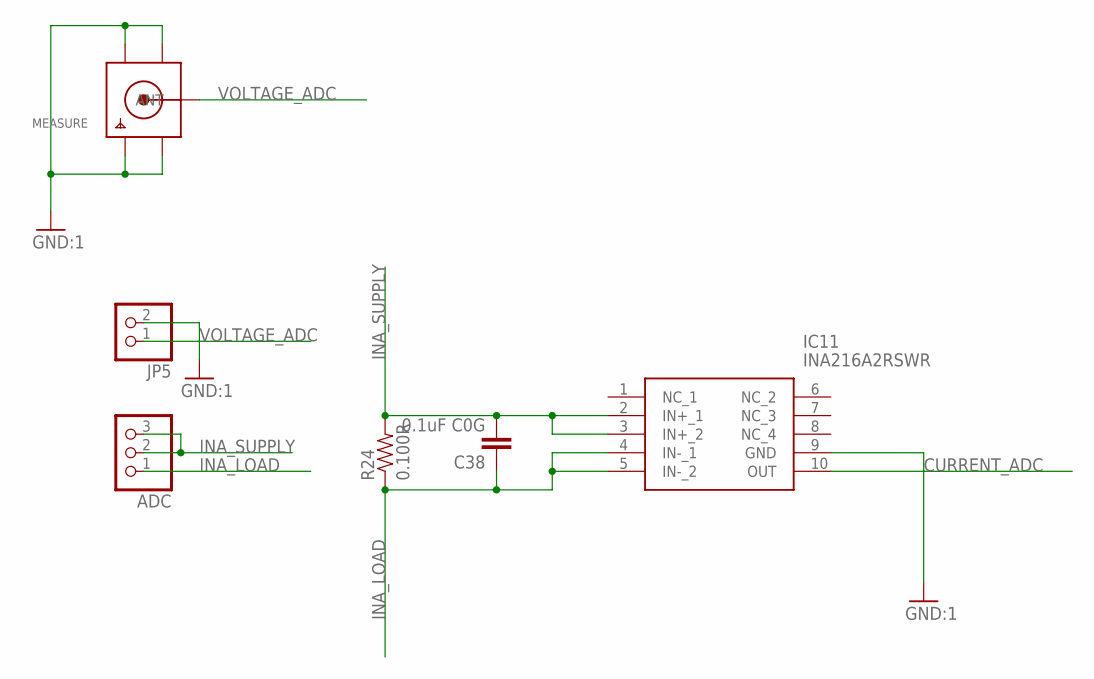
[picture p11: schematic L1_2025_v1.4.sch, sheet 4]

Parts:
ADC: PINHD-1X3:1; 1X03:1
C38: 0.1uF C0G; 0402-CAP
IC11: INA216A2RSWR
JP5: PINHD-1X2; 1X02
MEASURE: SMACONNECTOR_EDGE; SMA_EDGELAUNCH
R24: 0.100R; R2512

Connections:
CURRENT_ADC: IC11.10 (OUT); also elsewhere on the board
GND: IC11.9 (GND), JP5.2, MEASURE.GND@1 (GND4), MEASURE.GND@2 (GND3), MEASURE.GND@3 (GND2), MEASURE.GND@4 (GND1); also elsewhere on the board
INA_LOAD: ADC.1, C38.1, IC11.4 (IN-_1), IC11.5 (IN-_2), R24.1
INA_SUPPLY: ADC.2, ADC.3, C38.2, IC11.2 (IN+_1), IC11.3 (IN+_2), R24.2
VOLTAGE_ADC: JP5.1, MEASURE.P (ANT); also elsewhere on the board

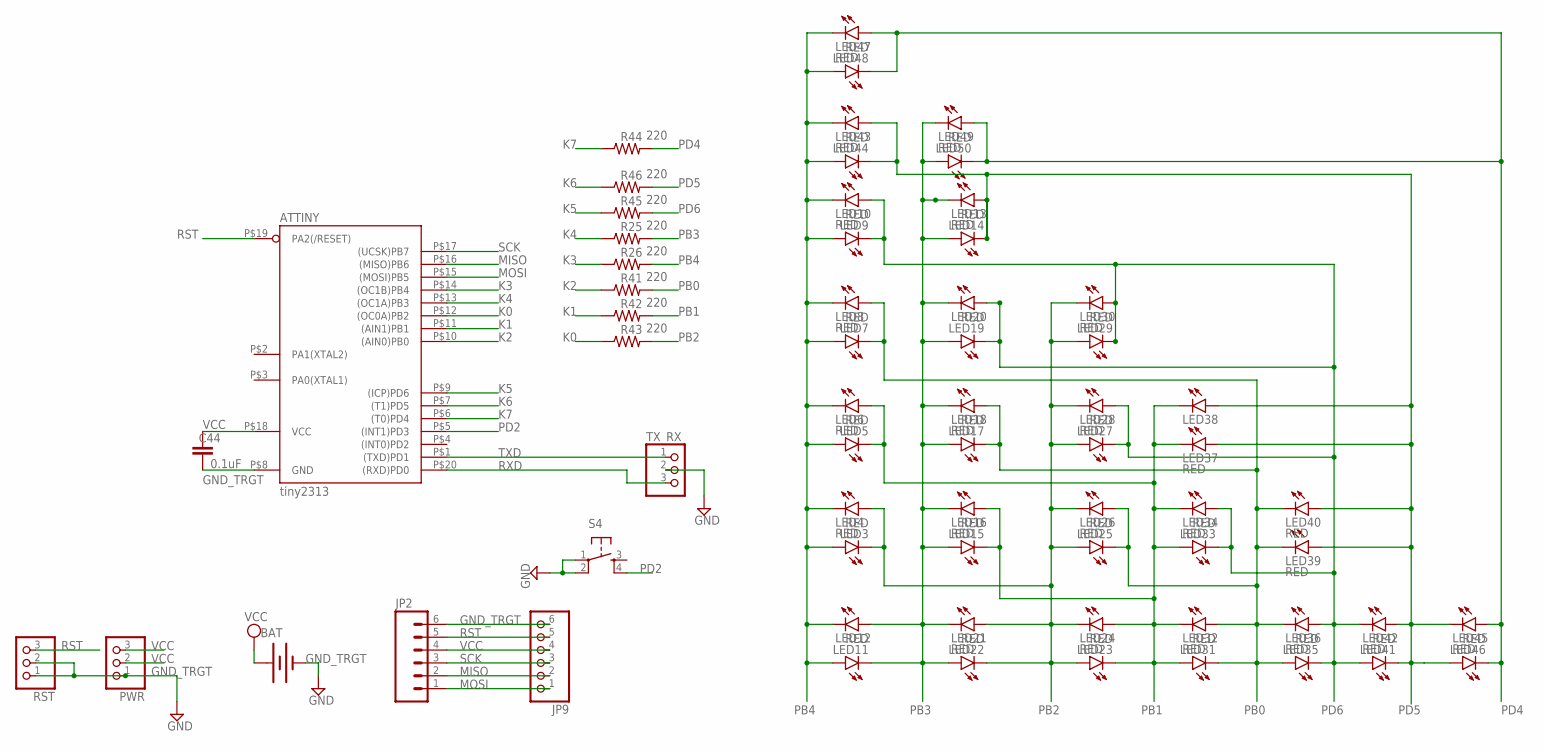
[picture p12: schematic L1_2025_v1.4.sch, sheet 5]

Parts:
ATTINY: tiny2313; MLF20
BAT: SPARKFUN_BATTERYSPARKFUN_BATTCOMM_20MM_LINX; SPARKFUN_BATTCOM_20MM_LINX
C44: 0.1uF; 0402-CAP
JP2: SPARKFUN-CONNECTORS_M06SMD-FEMALE-V2; SPARKFUN-CONNECTORS_1X06-SMD-FEMALE-V2
JP9: ADAFRUIT_PINHD-1X6CLEAN; ADAFRUIT_1X06-CLEAN
LED3, LED4, LED5, LED6, LED7, LED8, LED9, LED10, LED11, LED13, LED14, LED15, LED16, LED17, LED18, LED19, LED21, LED22, LED23, LED24, LED25, LED26, LED27, LED28, LED29, LED30, LED31, LED32, LED33, LED34, LED35, LED36, LED37, LED39, LED40, LED41, LED42, LED43, LED44, LED45, LED46, LED47, LED48, LED49, LED50: RED; CHIPLED_1206
LED12, LED20, LED38: LEDCHIPLED_1206:1; CHIPLED_1206
PWR: PINHD-1X3; 1X03
R25, R26, R41, R42, R43, R44, R45, R46: 220; 0805
RST: PINHD-1X3; 1X03
S4: TAC_SWITCHSMD; TACTILE_SWITCH_SMD:1
TX_RX: PINHD-1X3; 1X03

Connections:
GND_TRGT: ATTINY.P$8 (GND), BAT.2 (-), C44.1, JP2.6, JP9.6, PWR.1, RST.1, RST.2, S4.1, S4.2, TX_RX.2; also elsewhere on the board
K0: ATTINY.P$12 ((OC0A)PB2), R43.1
K1: ATTINY.P$11 ((AIN1)PB1), R42.1
K2: ATTINY.P$10 ((AIN0)PB0), R41.1
K3: ATTINY.P$14 ((OC1B)PB4), R26.1
K4: ATTINY.P$13 ((OC1A)PB3), R25.1
K5: ATTINY.P$9 ((ICP)PD6), R45.1
K6: ATTINY.P$7 ((T1)PD5), R46.1
K7: ATTINY.P$6 ((T0)PD4), R44.1
MISO: ATTINY.P$16 ((MISO)PB6), JP2.2, JP9.2
MOSI: ATTINY.P$15 ((MOSI)PB5), JP2.1, JP9.1
PB0: LED7.C, LED8.A, LED17.C, LED18.A, LED25.C, LED26.A, LED31.C, LED32.A, LED35.A, LED36.C, LED39.C, LED40.C, R41.2
PB1: LED5.C, LED6.A, LED15.C, LED16.A, LED23.C, LED24.A, LED31.A, LED32.C, LED33.A, LED34.C, LED37.C, LED38.C, R42.2
PB2: LED3.C, LED4.A, LED21.A, LED22.C, LED23.A, LED24.C, LED25.A, LED26.C, LED27.A, LED28.C, LED29.A, LED30.C, R43.2
PB3: LED11.C, LED12.A, LED13.C, LED14.A, LED15.A, LED16.C, LED17.A, LED18.C, LED19.A, LED20.C, LED21.C, LED22.A, LED49.C, LED50.A, R25.2
PB4: LED3.A, LED4.C, LED5.A, LED6.C, LED7.A, LED8.C, LED9.A, LED10.C, LED11.A, LED12.C, LED43.C, LED44.A, LED47.C, LED48.A, R26.2
PD2: ATTINY.P$5 ((INT1)PD3), S4.4
PD4: LED45.A, LED46.C, LED47.A, LED48.C, LED49.A, LED50.C, R44.2
PD5: LED13.A, LED14.C, LED37.A, LED38.A, LED39.A, LED40.A, LED41.C, LED42.A, LED43.A, LED44.C, LED45.C, LED46.A, R46.2
PD6: LED9.C, LED10.A, LED19.C, LED20.A, LED27.C, LED28.A, LED29.C, LED30.A, LED33.C, LED34.A, LED35.C, LED36.A, LED41.A, LED42.C, R45.2
RST: ATTINY.P$19 (PA2(/RESET)), JP2.5, JP9.5, RST.3
RXD: ATTINY.P$20 ((RXD)PD0), TX_RX.3
SCK: ATTINY.P$17 ((UCSK)PB7), JP2.3, JP9.3
TXD: ATTINY.P$1 ((TXD)PD1), TX_RX.1
VCC: ATTINY.P$18 (VCC), BAT.1 (+), C44.2, JP2.4, JP9.4, PWR.2, PWR.3

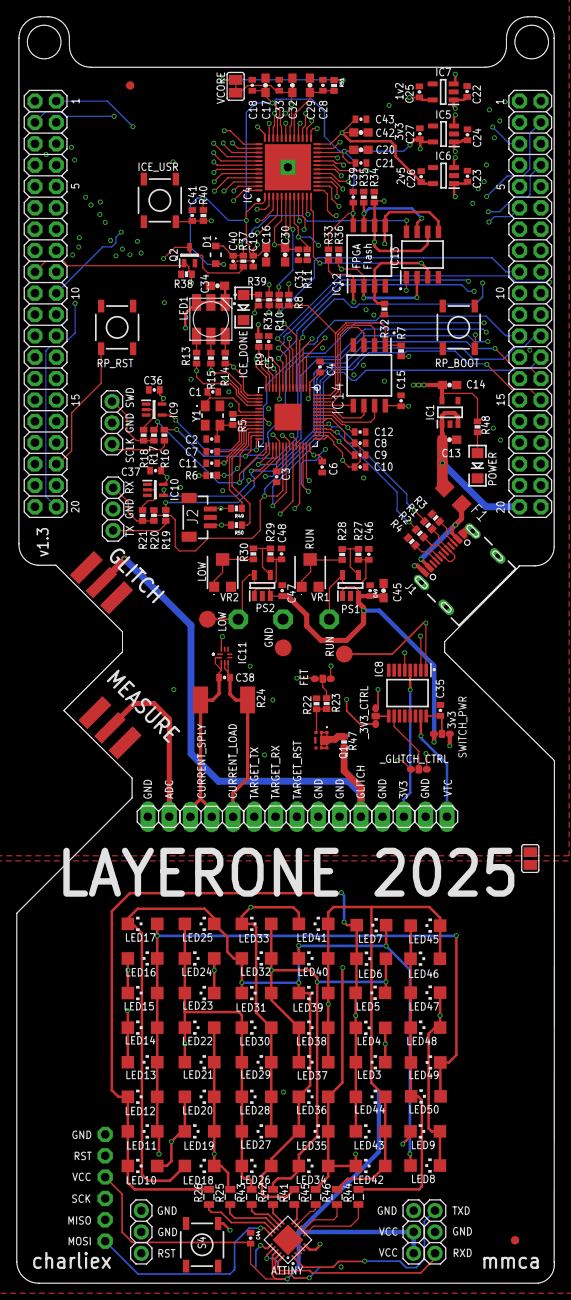
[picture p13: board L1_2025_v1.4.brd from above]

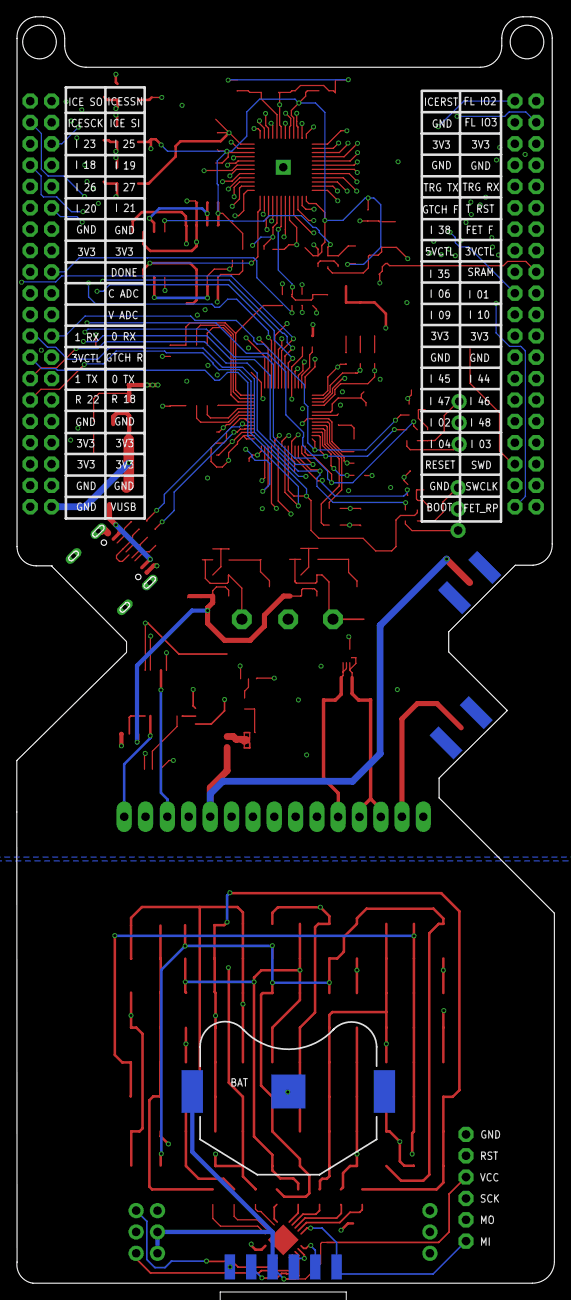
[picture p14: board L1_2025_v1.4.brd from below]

Board: 4 copper layers, 64.0 x 150.7 mm, 211 parts (2 on the bottom side), 140 nets.

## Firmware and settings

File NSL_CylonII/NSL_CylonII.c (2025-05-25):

#include <avr/io.h> 
#include <avr/eeprom.h> 
#include <avr/interrupt.h>
#include <avr/pgmspace.h>

#include <util/delay.h>

#include <stdlib.h>

#define shortdelay(); 			asm("nop\n\tnop\n\t");

#define TIMER1_PRESCALE_1 		(1)
#define TIMER1_PRESCALE_8 		(2)
#define TIMER1_PRESCALE_64 		(3)
#define TIMER1_PRESCALE_256		(4)
#define TIMER1_PRESCALE_1024	(5)

#define MIN_OF(x,y) ((x) < (y) ? (x) : (y))
#define MAX_OF(x,y) ((x) > (y) ? (x) : (y))

#define GET_BIT(a,n)    ((a >> n) & 1)
#define SET_BIT(a,n)    (a|=(1<<n))
#define CLR_BIT(a,n)    (a&=~(1<<n))
#define SWITCH_BIT(a,n) (a^=(1<<n))
#define IS_BIT_SET(a,n) (a & (1<<n))
#define IS_BIT_CLR(a,n) (~(a & (1<<n)))

// 		PORTB,DDRB,PINB

#define ddrb(r,c)  charlieplex[ (r*(3*4)) + ((c*3)+1) ]
#define pinb(r,c)  charlieplex[ (r*(3*4)) + ((c*3)+2) ]
#define portb(r,c) charlieplex[ (r*(3*4)) + ((c*3)+0) ]

#define HEX__(n) 0x##n##LU

/* 8-bit conversion function */
#define B8__(x) ((x&0x0000000FLU)?1:0)	\
	+((x&0x000000F0LU)?2:0)		\
	+((x&0x00000F00LU)?4:0)		\
	+((x&0x0000F000LU)?8:0)		\
	+((x&0x000F0000LU)?16:0)	\
	+((x&0x00F00000LU)?32:0)	\
	+((x&0x0F000000LU)?64:0)	\
	+((x&0xF0000000LU)?128:0)

/* *** user macros ***/

/* for upto 8-bit binary constants */
#define B8(d) ((unsigned char)B8__(HEX__(d)))

/* for upto 16-bit binary constants, MSB first */
#define B16(dmsb,dlsb) (((unsigned short)B8(dmsb)<<	+ B8(dlsb)))

/* for upto 32-bit binary constants, MSB first */
#define B32(dmsb,db2,db3,dlsb) (((unsigned long)B8(dmsb)<<24)	 \
	+ ((unsigned long)B8(db2)<<16) \
	+ ((unsigned long)B8(db3)<<	 \
	+ B8(dlsb))



//  state definitions for each individual LED
// A5  A2  A1  A0  A4  A3
// PD6 PB0 PB1 PB2 PB3 PB4  

// 00 = LOW
// 01 = HIGH
// 11 = X (input)


#if 1

static const unsigned char PROGMEM led30[] = {

	B8( 1111),  B8(11110001 ),		// LED1
	B8( 1111) , B8(11110100 ),		// LED2
	B8( 1111) , B8(11001101 ),		// LED3
	B8( 1111) , B8(11011100 ),		// LED4
	B8( 1111) , B8(00111101 ),		// LED5
	B8( 1111) , B8(01111100 ),		// LED6

	B8( 1111) , B8(11000111 ),		// LED11
	B8( 1111) , B8(11010011 ),		// LED12
	B8( 1111) , B8(00110111 ),		// LED13
	B8( 1111) , B8(01110011 ),		// LED14
	B8( 1100) , B8(11110111 ),		// LED15
	B8( 1101) , B8(11110011 ),		// LED16

	B8( 1111) , B8(00011111 ),		// LED19
	B8( 1111) , B8(01001111 ),		// LED20
	B8( 1100),  B8(11011111 ),		// LED21
	B8( 1101) , B8(11001111 ),		// LED22
	B8( 0011) , B8(11011111 ),		// LED23
	B8( 0111) , B8(11001111 ),		// LED24

	B8( 1100) , B8(01111111 ),		// LED25
	B8( 1101) , B8(00111111 ),		// LED26
	B8( 0011) , B8(01111111 ),		// LED27
	B8( 0111) , B8(00111111 ),		// LED28
	B8( 1100),  B8(11111101 ),		// LED7
	B8( 1101) , B8(11111100 ),		// LED8


	B8( 0001) , B8(11111111 ),		// LED29
	B8( 0100) , B8(11111111 ),		// LED30
	B8( 0011) , B8(11110111 ),		// LED17
	B8( 0111) , B8(11110011 ),		// LED18
	B8( 0011) , B8(11111101 ),		// LED9
	B8( 0111) , B8(11111100 ),		// LED10
};

#else

static const unsigned char PROGMEM led30[] = {

	B8( 1111) , B8(11110100 ),		// LED2
	B8( 1111),  B8(11110001 ),		// LED1
	B8( 1111) , B8(11011100 ),		// LED4
	B8( 1111) , B8(11001101 ),		// LED3
	B8( 1111) , B8(01111100 ),		// LED6
	B8( 1111) , B8(00111101 ),		// LED5
	
	B8( 1111) , B8(11010011 ),		// LED12
	B8( 1111) , B8(11000111 ),		// LED11
	B8( 1111) , B8(01110011 ),		// LED14
	B8( 1111) , B8(00110111 ),		// LED13
	B8( 1101) , B8(11110011 ),		// LED16
	B8( 1100) , B8(11110111 ),		// LED15
	
	B8( 1111) , B8(01001111 ),		// LED20
	B8( 1111) , B8(00011111 ),		// LED19
	B8( 1101) , B8(11001111 ),		// LED22
	B8( 1100),  B8(11011111 ),		// LED21
	B8( 0111) , B8(11001111 ),		// LED24
	B8( 0011) , B8(11011111 ),		// LED23

	B8( 1101) , B8(00111111 ),		// LED26
	B8( 1100) , B8(01111111 ),		// LED25
	B8( 0111) , B8(00111111 ),		// LED28
	B8( 0011) , B8(01111111 ),		// LED27
	B8( 1101) , B8(11111100 ),		// LED8
	B8( 1100),  B8(11111101 ),		// LED7

	B8( 0100) , B8(11111111 ),		// LED30
	B8( 0001) , B8(11111111 ),		// LED29
	B8( 0111) , B8(11110011 ),		// LED18
	B8( 0011) , B8(11110111 ),		// LED17
	B8( 0111) , B8(11111100 ),		// LED10
	B8( 0011) , B8(11111101 ),		// LED9
};
#endif


unsigned int X = 0;
signed char XDIR =1;

// this routine is written to help understand how the process works, not be fast.
void SetRC( unsigned char R,unsigned char C ) 
{	
	unsigned char b1,b2;
	unsigned char portb, ddrb,portd6=2;

	// get current values, Can't cache PORTD/DDRD since the sound interrupt can change, should cache DDRD6/PORTD6 instead
	portb = PORTB;
	ddrb = DDRB;

//	read two values from array, we use pgm_read_byte because the data is in program memory space
// its 6*2 because there are 6 leds in each column, and two bytes per led
	b1 = pgm_read_byte(&led30[ (R*(6*2))+(C*2)   ] ) ;
	b2 = pgm_read_byte(&led30[((R*(6*2))+(C*2))+1] ) ;

// if  bit positions 32 in b1 == 11 then set to don't care (input ) tristate for PD6
	if( IS_BIT_SET( b1,3 ) && IS_BIT_SET( b1,2 ) ) {

		CLR_BIT(DDRD,6 );

	} else { 

		// otherwise it is set to an output
		SET_BIT(DDRD ,6 );
	}

// if 10 == 11 then set to don't care (input ) tristate for PB0
	if( GET_BIT( b1,1 )==1 && GET_BIT( b1,0 )==1 ) {

		CLR_BIT(ddrb,0 );

	} else { 

		// otherwise its an output
		SET_BIT(ddrb ,0 );
	}

// if 76 == 11 then set to don't care (input ) tristate  for PB1
	if( GET_BIT( b2,7 )==1 && GET_BIT( b2,6 )==1 ) {

		CLR_BIT(ddrb,1 );

	} else { 

		// otherwise its an output
		SET_BIT(ddrb ,1 );
	}

// if 54 == 11 then set to don't care (input ) tristate for PB2
	if( GET_BIT( b2,5 )==1 && GET_BIT( b2,4 )==1 ) {

		CLR_BIT(ddrb,2 );

	} else { 

		// otherwise its an output
		SET_BIT(ddrb ,2 );
	}

// if 32 == 11 then set to don't care (input ) tristate for PB3
	if( GET_BIT( b2,3 )==1 && GET_BIT( b2,2 )==1 ) {

		CLR_BIT(ddrb,3 );

	} else { 

		// otherwise its an output
		SET_BIT(ddrb ,3 );
	}

// if 10 == 11 then set to don't care (input ) tristate for PB4
	if( GET_BIT( b2,1 )==1 && GET_BIT( b2,0 )==1 ) {

		CLR_BIT(ddrb,4 );

	} else { 

		// otherwise its an output
		SET_BIT(ddrb ,4 );
	}

/// all of the DDR's are set

// if 32 == 00 then set to low for PD6
	if( GET_BIT( b1,3 )==0 && GET_BIT( b1,2 )==0 ) {

//		CLR_BIT(PORTD,6 ); //set to off

		portd6 = 0;

	// if 32 == 01 then set to high for PD6
	} else if( GET_BIT( b1,3 )==0 && GET_BIT( b1,2 )== 1) { 

		// set to on
		//SET_BIT(PORTD ,6 );
		portd6 = 1;
	}

// if 10 == 00 then set to low for PB0
	if( GET_BIT( b1,1 )==0 && GET_BIT( b1,0 )==0 ) {

		CLR_BIT(portb,0); //set to off

	// if 32 == 01 then set to high for PB0
	} else if( GET_BIT( b1,1 )==0 && GET_BIT( b1,0 )==1 ) { 

		// set to on
		SET_BIT(portb ,0 );
	}

// if 76 == 00 then set to low for PB1
	if( GET_BIT( b2,7 )==0 && GET_BIT( b2,6 )==0 ) {

		CLR_BIT(portb,1); //set to off

	// if 32 == 01 then set to high for PB1
	} else if( GET_BIT( b2,7 )==0 && GET_BIT( b2,6 ) ==1 ) { 

		// set to on
		SET_BIT(portb ,1 );
	}


// if 54 == 00 then set to low for PB2
	if( GET_BIT( b2,5 )==0 && GET_BIT( b2,4 )==0 ) {

		CLR_BIT(portb,2); //set to off

	// if 32 == 01 then set to high for PB2
	} else if( GET_BIT( b2,5 )==0 && GET_BIT( b2,4 )==1 ) { 

		// set to on
		SET_BIT(portb ,2 );
	}

// if 32 == 00 then set to low for PB3
	if( GET_BIT( b2,3 )==0 && GET_BIT( b2,2 )==0 ) {

		CLR_BIT(portb,3); //set to off

	// if 32 == 01 then set to high for PB3
	} else if( GET_BIT( b2,3 ) ==0 && GET_BIT( b2,2 )==1 ) { 

		// set to on
		SET_BIT(portb ,3 );
	}

// if 10 == 00 then set to low for PB4
	if( GET_BIT( b2,1 )==0 && GET_BIT( b2,0 )==0 ) {

		CLR_BIT(portb,4); //set to off

// if 32 == 01 then set to high for PB4
	} else if( GET_BIT( b2,1)==0 && GET_BIT( b2,0 )==1 ) { 

		// set to on
		SET_BIT(portb ,4 );
	}

	//set all at once, stops it from flickering 
	PORTB = portb;
	DDRB = ddrb;

	if(portd6 == 1 ) { 
	
		SET_BIT(PORTD ,6 );

	} else	if(portd6 == 0 ) {

		CLR_BIT(PORTD,6 ); 
	}
}

static const unsigned char pattern[] PROGMEM =
{ 
//	5,0,0,0,0,0,

//6x5

	0,0,0,0,0,0,
	0,0,0,0,0,0,
	0,0,0,0,0,0,
	0,0,0,0,0,0,


	1,1,1,1,1,1,
	1,0,0,0,0,1,
	1,0,0,0,0,1,

	0,0,0,0,0,0,

	1,1,1,1,1,1,
    0,0,0,0,1,0,
    0,0,0,1,0,0,
    0,0,1,0,0,0,
	1,1,1,1,1,1,
  
	0,0,0,0,0,0,

	1,0,0,1,1,1,
	1,0,1,1,0,1,
	1,0,1,1,0,1,
	1,0,1,1,0,1,
	1,1,1,0,0,1,

	0,0,0,0,0,0,

	1,1,1,1,1,1,
	1,0,0,0,0,0,
	1,0,0,0,0,0,
	1,0,0,0,0,0,

	0,0,0,0,0,0,

	1,0,0,0,0,1,
	1,0,0,0,0,1,
	1,1,1,1,1,1,

	0,0,0,0,0,0,
	0,0,0,0,0,0,
	0,0,0,0,0,0,
	0,0,0,0,0,0,


	1,1,1,1,1,1,
	1,1,1,1,1,1,
	1,1,1,1,1,1,
	1,1,1,1,1,1,
	1,1,1,1,1,1,
	1,1,1,1,1,1,
	1,1,1,1,1,1
};


// Speaker drive interrupt
SIGNAL( SIG_TIMER1_COMPA ) 
{
	// toggle speaker on/off
	//SWITCH_BIT( PORTD , 4 );

	X += XDIR;

	if (X > 10000 ) { 
		XDIR = -((rand()%9)+1);
	} else if ( X < 20) {
		XDIR = ((rand()%9)+1);
	}

	OCR1A = X+(rand()%100);
}


int main(void)
{
	unsigned int x;;
	unsigned char R,C;
	unsigned long i;

	// setup timer
	TCCR1B = (1 << WGM12) | TIMER1_PRESCALE_1;
	OCR1A = (uint16_t)1000;
	TIMSK |= 1 << OCIE1A;   // Output Compare Interrupt Enable (timer 1, OCR1A) 

//  speaker off (eats power otherwise)
	DDRD = 0xff;
	PIND = 0x0;
	PORTD = 0x10; 
	DDRB = 0;

// switch on interrupts ( start speaker )

	//sei();


// index to start
	i = 0;

	X = 0;
	
	while( 1 ) {
		for ( R= 0 ; R < 5 ; R ++ ) {
			for ( C= 0 ; C < 6 ; C ++ ) {

				//SetRC(R,C);
				//_delay_ms(800);
	
				DDRB = rand();
				PORTB = rand();
				DDRB = rand();
				PORTD = rand();



			}
		}
	}

	for(;;) {	

		for ( x = 0 ; x < 150; x ++) {

			for ( R= 0 ; R < 5 ; R ++ ) {

				for ( C= 0 ; C < 6 ; C ++ ) {

					unsigned char code;

					if ( i < sizeof( pattern) ) {
						
						// fetch value
						code = pgm_read_byte ( &pattern[i]  );

					} else {

						i = 0;
					}
	
					// if first column
					if (C == 0 && code > 1 ) {

						// skip rest of row ( i++ later makes it 6)
						i += 6;

					}
					else
						if( code  ) {
							SetRC(R,C);
						} 


					i++;

				}
			}

			// go back to beginning of pattern, repeat for speed%10
			i -= (5*6);
	
		}	

		// skip a row
		i += 6;

		if( i >=  sizeof(pattern) ) {
			i = 0;
		}
	}
}

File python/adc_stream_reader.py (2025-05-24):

#!/usr/bin/env python3
"""
ADC Stream Reader for LayerOne 2025 Badge

This script reads and decodes the ADC stream from the LayerOne 2025 badge.
The badge streams ADC0 and ADC1 values at 1000Hz over USB CDC2.

Packet format:
- Byte 0: Header byte (0xAA) for synchronization
- Byte 1: Sequence number (increments with each packet)
- Byte 2: Low 8 bits of ADC0
- Byte 3: High 4 bits of ADC0 and low 4 bits of ADC1
- Byte 4: High 8 bits of ADC1

Usage:
    python adc_stream_reader.py [port]

    If port is not specified, the script will try to auto-detect the port.
"""

import sys
import time
import re
import serial
import serial.tools.list_ports
import matplotlib.pyplot as plt
from matplotlib.animation import FuncAnimation
import numpy as np
import threading

# constants
HEADER_BYTE = 0xAA
PACKET_SIZE = 5
BUFFER_SIZE = 1000  # number of samples to display
RECONNECT_DELAY = 2  # seconds to wait between reconnection attempts

# global variables for plotting
adc0_values = np.zeros(BUFFER_SIZE)
adc1_values = np.zeros(BUFFER_SIZE)
lost_packets = 0
total_packets = 0
connection_status = {"connected": False, "port": None}

def find_macos_badge_port_using_system_commands():
    """Use macOS system commands to find the ADC Stream Interface port."""
    import subprocess
    import re
    import os
    
    # Check if the badge is connected using system_profiler
    try:
        result = subprocess.run(['system_profiler', 'SPUSBDataType'], capture_output=True, text=True)
        if "GLiTCh Badge 2025" not in result.stdout:
            print("GLiTCh Badge 2025 not found using system_profiler.")
            return None
    except Exception as e:
        print(f"Error running system_profiler: {e}")
        return None
    
    # Try to find the ADC Stream Interface using ioreg
    try:
        # Get interface names
        result = subprocess.run(['ioreg', '-c', 'IOUSBHostInterface', '-r'], capture_output=True, text=True)
        
        # Look for ADC Stream Interface
        match = re.search(r'"kUSBString" = "ADC Stream Interface"', result.stdout)
        if match:
            print("Found ADC Stream Interface in ioreg output.")
            
            # Now find the corresponding serial port
            try:
                # Get a list of all usbmodem devices
                devices = os.listdir('/dev')
                modem_devices = [d for d in devices if d.startswith('cu.usbmodem')]
                
                # Look for port ending with 5
                for device in modem_devices:
                    if device.endswith('5') or '1234565' in device:
                        port = f"/dev/{device}"
                        print(f"Found ADC Stream Interface port using system commands: {port}")
                        return port
                
                print("No port ending with '5' found in /dev")
            except Exception as e:
                print(f"Error listing /dev directory: {e}")
    except Exception as e:
        print(f"Error running ioreg: {e}")
    
    return None

def find_windows_badge_port_using_system_commands():
    """Use Windows system commands to find the ADC Stream Interface port."""
    import subprocess
    import re
    
    try:
        # Use PowerShell to get USB devices
        result = subprocess.run(['powershell', '-command',
                                '& {Get-PnpDevice | Where-Object { $_.FriendlyName -like "*GLiTCh Badge 2025*" } | Format-List}'],
                                capture_output=True, text=True)
        
        if "GLiTCh Badge 2025" not in result.stdout:
            print("GLiTCh Badge 2025 not found using PowerShell.")
            return None
            
        # Get COM ports
        result = subprocess.run(['powershell', '-command',
                                '& {Get-PnpDevice -Class Ports | Format-List}'],
                                capture_output=True, text=True)
        
        # Look for COM port with ADC Stream Interface
        match = re.search(r'FriendlyName.*ADC Stream Interface.*\(COM(\d+)\)', result.stdout)
        if match:
            port = f"COM{match.group(1)}"
            print(f"Found ADC Stream Interface port using system commands: {port}")
            return port
            
        # Look for COM5 (common for ADC Stream Interface)
        match = re.search(r'FriendlyName.*GLiTCh Badge 2025.*\(COM(\d+)\)', result.stdout)
        if match and match.group(1) == "5":
            port = "COM5"
            print(f"Found ADC Stream Interface port using system commands: {port}")
            return port
    except Exception as e:
        print(f"Error running PowerShell commands: {e}")
    
    return None

def find_linux_badge_port_using_system_commands():
    """Use Linux system commands to find the ADC Stream Interface port."""
    import subprocess
    import re
    
    try:
        # Check if the badge is connected using lsusb
        result = subprocess.run(['lsusb'], capture_output=True, text=True)
        if "1209:2025" not in result.stdout:
            print("GLiTCh Badge 2025 not found using lsusb.")
            return None
            
        # Get more detailed USB info
        result = subprocess.run(['lsusb', '-v', '-d', '1209:2025'], capture_output=True, text=True)
        
        # Look for ADC Stream Interface
        interfaces = re.findall(r'iInterface\s+\d+\s+(.*)', result.stdout)
        adc_interface_found = False
        for interface in interfaces:
            if "ADC Stream Interface" in interface:
                adc_interface_found = True
                break
                
        if adc_interface_found:
            # Find ACM devices
            result = subprocess.run(['ls', '-la', '/dev/ttyACM*'], capture_output=True, text=True)
            
            # Look for ttyACM2 (common for ADC Stream Interface)
            for line in result.stdout.splitlines():
                if '/dev/ttyACM2' in line:
                    print(f"Found ADC Stream Interface port using system commands: /dev/ttyACM2")
                    return '/dev/ttyACM2'
    except Exception as e:
        print(f"Error running Linux commands: {e}")
    
    return None

def port_exists(port_name):
    """check if a port exists in the system."""
    ports = [p.device for p in serial.tools.list_ports.comports()]
    return port_name in ports
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

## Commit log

2025-05-24 added schematics
    [L1_2025_v1.4.brd, L1_2025_v1.4.sch]
2025-05-25 Add files via upload
    test code for lower half
    [BOM.xls, NSL_CylonII-pickobear.csv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]
2025-05-25 Add files via upload
    prebuilt pico ice for rpi chip on badge
2025-05-26 Add files via upload
    fixed bug in loops
    added new trigger command ( needs test suite added ) so needs validation
    # gpio test script
    print "Testing GPIO pins hello..."
    # test output pins
    pin 0 out
    pin 2 out
    pin 25 out
    pin 25 high
    pin 25 low
    loop 4
    pin 0 high
    pin 2 low
    sleep 10ns
    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
2025-08-24 added LA mode
    added simple low speed logic analyser mode, about 10khz for gpio 0-11
    enable with command
    adc_stream la
    switch back to adc
    adc_stream adc
    use the python test code logic_analyser.py
    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
2025-08-24 fix pwm leds
    leds weren't correctly pwming
